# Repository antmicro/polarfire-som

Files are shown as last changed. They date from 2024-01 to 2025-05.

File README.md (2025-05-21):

# PolarFire SoM

Copyright (c) 2023-2025 [Antmicro](https://www.antmicro.com)

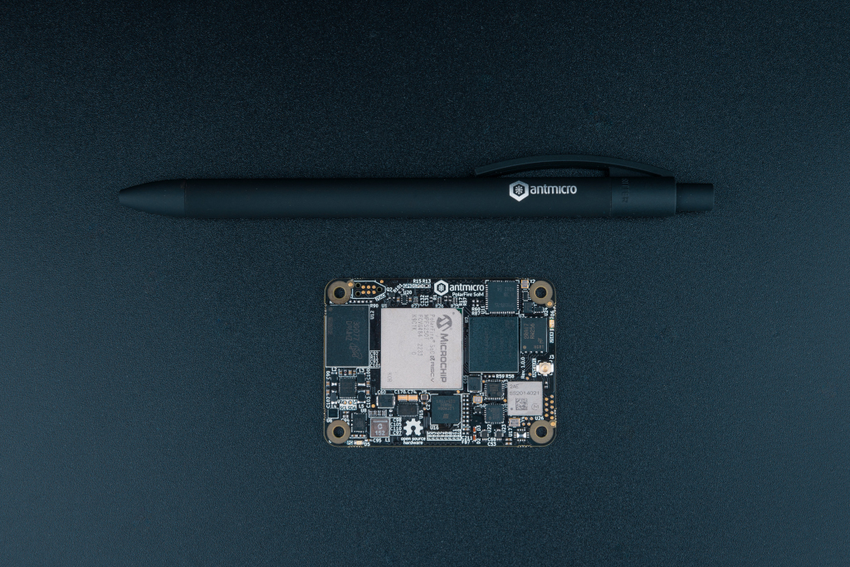
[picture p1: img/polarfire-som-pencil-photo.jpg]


## Overview

This project contains open hardware design files for the Antmicro PolarFire System on Module (SoM) built around Microchip [PolarFire MPFS250T](https://www.microchip.com/en-us/product/mpfs250t) RISC-V System on Chip.
The SoM exposes two 100-pin high density connectors with signal assignment that is electrically compatible with [Raspberry Pi Compute Module 4](https://datasheets.raspberrypi.com/cm4/cm4-datasheet.pdf).

The PCB design files were prepared in KiCad 7.

## Key features

* PolarFire SoC MPFS250T
* 2 GB LPDDR4-1866 SDRAM
* 8 GB eMMC flash memory
* Compact size: 55x40mm 
* Gigabit Ethernet PHY (Ti/[DP83867ISRGZR](https://www.ti.com/lit/gpn/DP83867IS))
* 4-lane PCIe (via MPFS250T built-in XCVR transceivers)
* 2.4 GHz, 5.0 GHz IEEE 802.11 b/g/n/ac WiFi module (Murata/[LBEE5PK2AE](https://www.murata.com/en-eu/products/connectivitymodule/wi-fi-bluetooth/overview/lineup/type2ae))
* Bluetooth 5.2 module (Murata/LBEE5PK2AE)
* HDMI output
* 4-lane MIPI DSI and 4-lane MIPI CSI-2 exposed via Lattice [CrossLink](https://www.latticesemi.com/Products/FPGAandCPLD/CrossLink) (LIF-MD6000-6JMG80I) companion IC
* Additional 2-lane MIPI CSI-2 camera port, when working in 1.8V logic
* On-board power sequencing and voltage regulation based on a single 5V supply

## Project structure

The main directory contains KiCad PCB project files, a LICENSE, and a README.
The remaining files are stored in the following directories:

* `doc` - contains schematics in PDF format
* `assets` - contains visual assets for showcasing this design on [Open Hardware Portal](https://openhardware.antmicro.com).
* `img` - contains graphics for this README

## Licensing

This project is published under the [Apache-2.0](LICENSE) license.

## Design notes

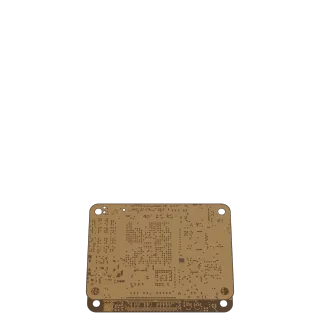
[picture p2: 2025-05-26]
assets/previews/layer14_thumbnail.webp

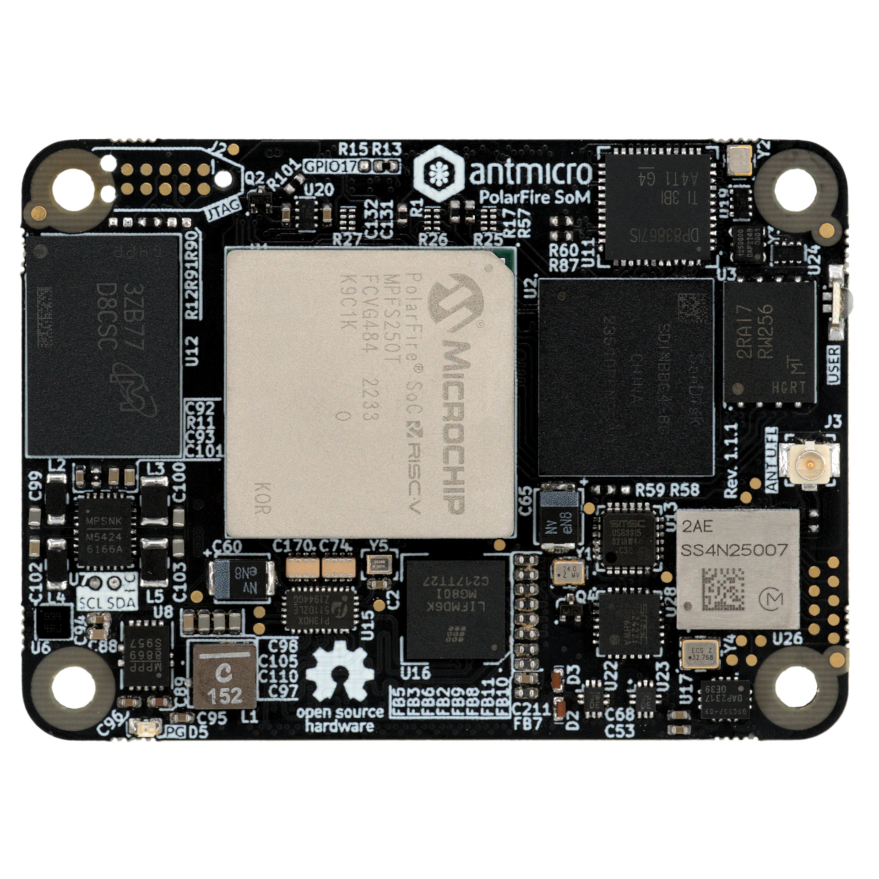
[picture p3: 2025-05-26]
assets/previews/orthoT_photo.png

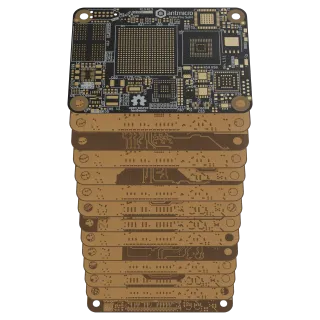
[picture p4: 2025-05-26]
assets/previews/layer1_thumbnail.webp

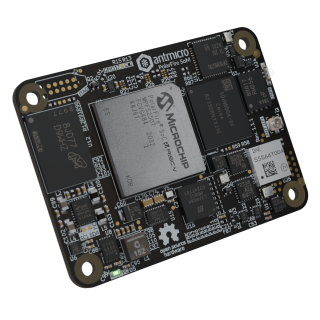
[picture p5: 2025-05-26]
assets/previews/leftT_thumbnail.png

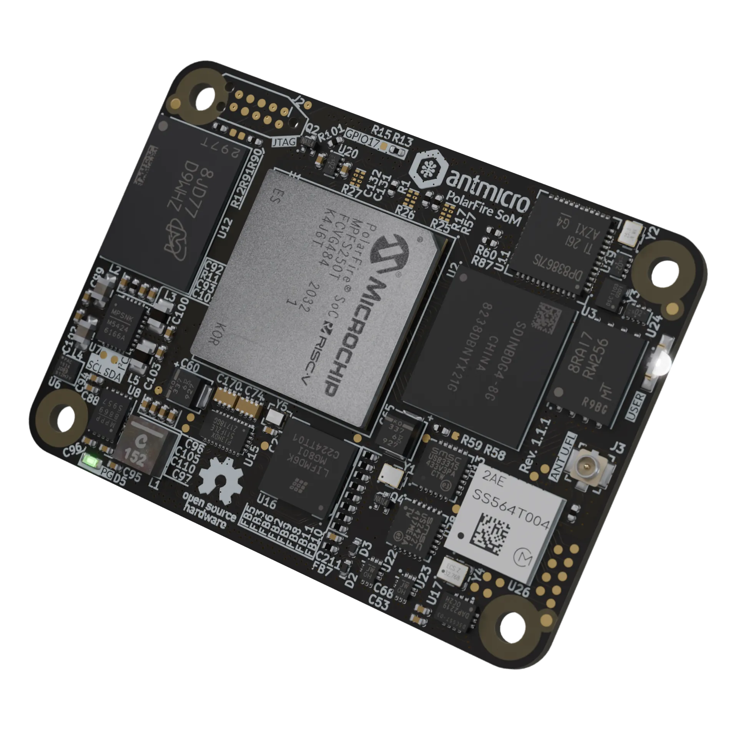
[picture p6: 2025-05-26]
assets/previews/rightT.webp

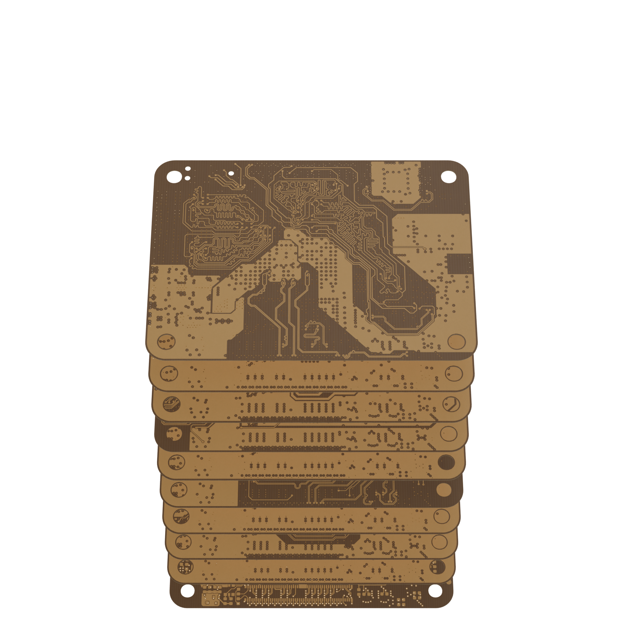
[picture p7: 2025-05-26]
assets/previews/layer6.png

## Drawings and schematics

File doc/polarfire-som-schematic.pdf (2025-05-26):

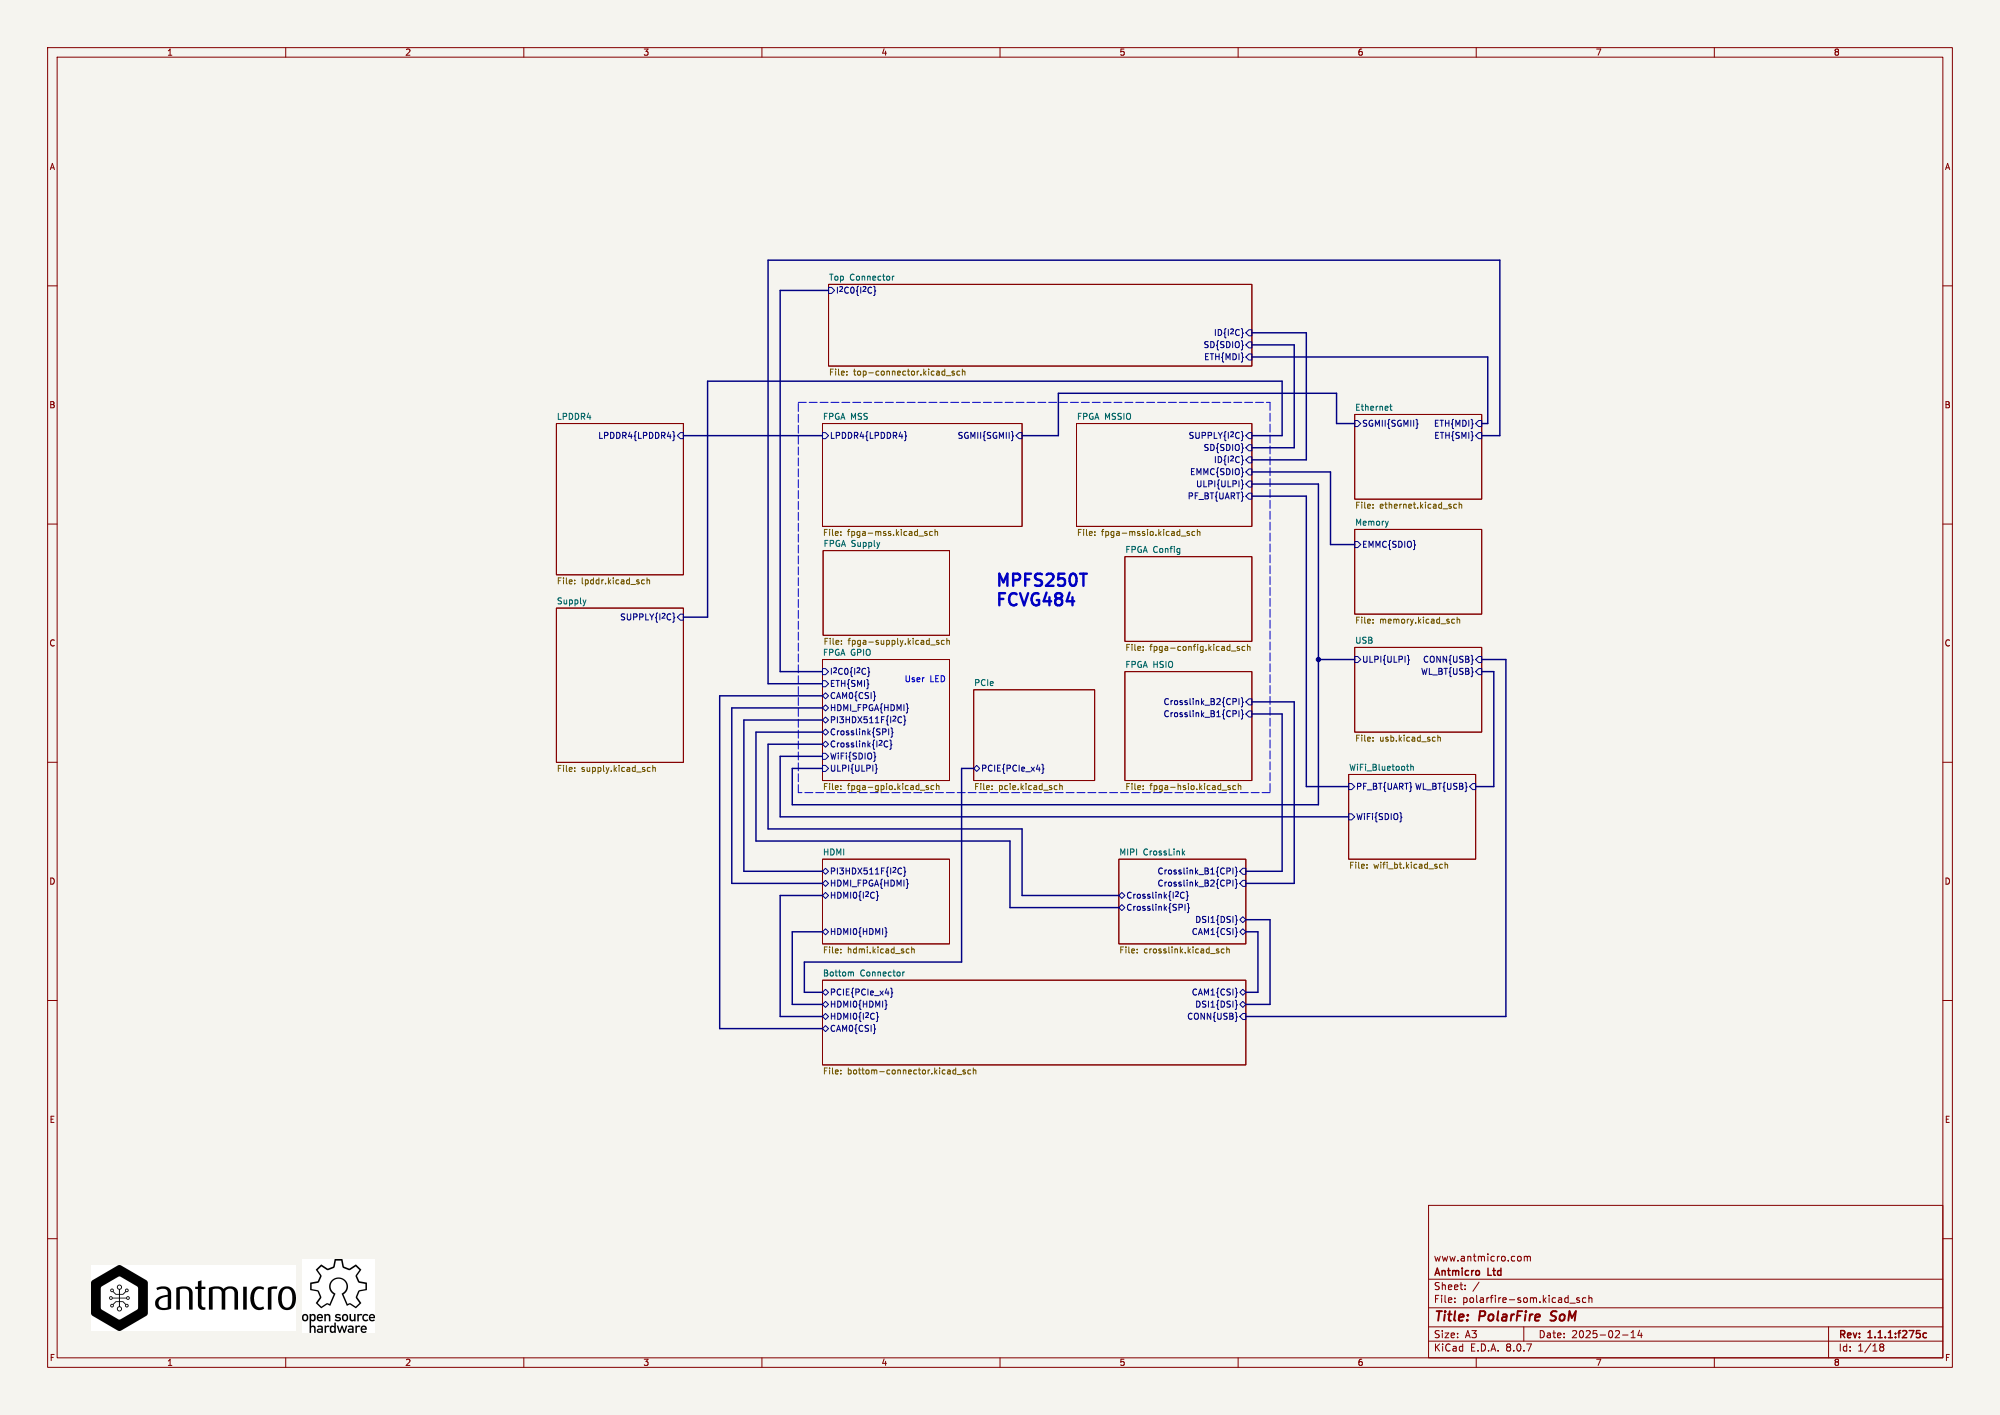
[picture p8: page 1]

Top Connector File: top-connector.kicad_sch

SD{SDIO}
ETH{SMI} Ethernet File: ethernet.kicad_sch ETH{MDI}

File: usb.kicad_sch EMMC{SDIO}

File: fpga-mssio.kicad_sch FPGA Config File: fpga-config.kicad_sch FPGA Supply File: fpga-supply.kicad_sch

ULPI{ULPI} FPGA GPIO

Crosslink{SPI} MIPI CrossLink File: crosslink.kicad_sch PCIE{PCIe_x4}

Id: 1/18 Title: PolarFire SoM

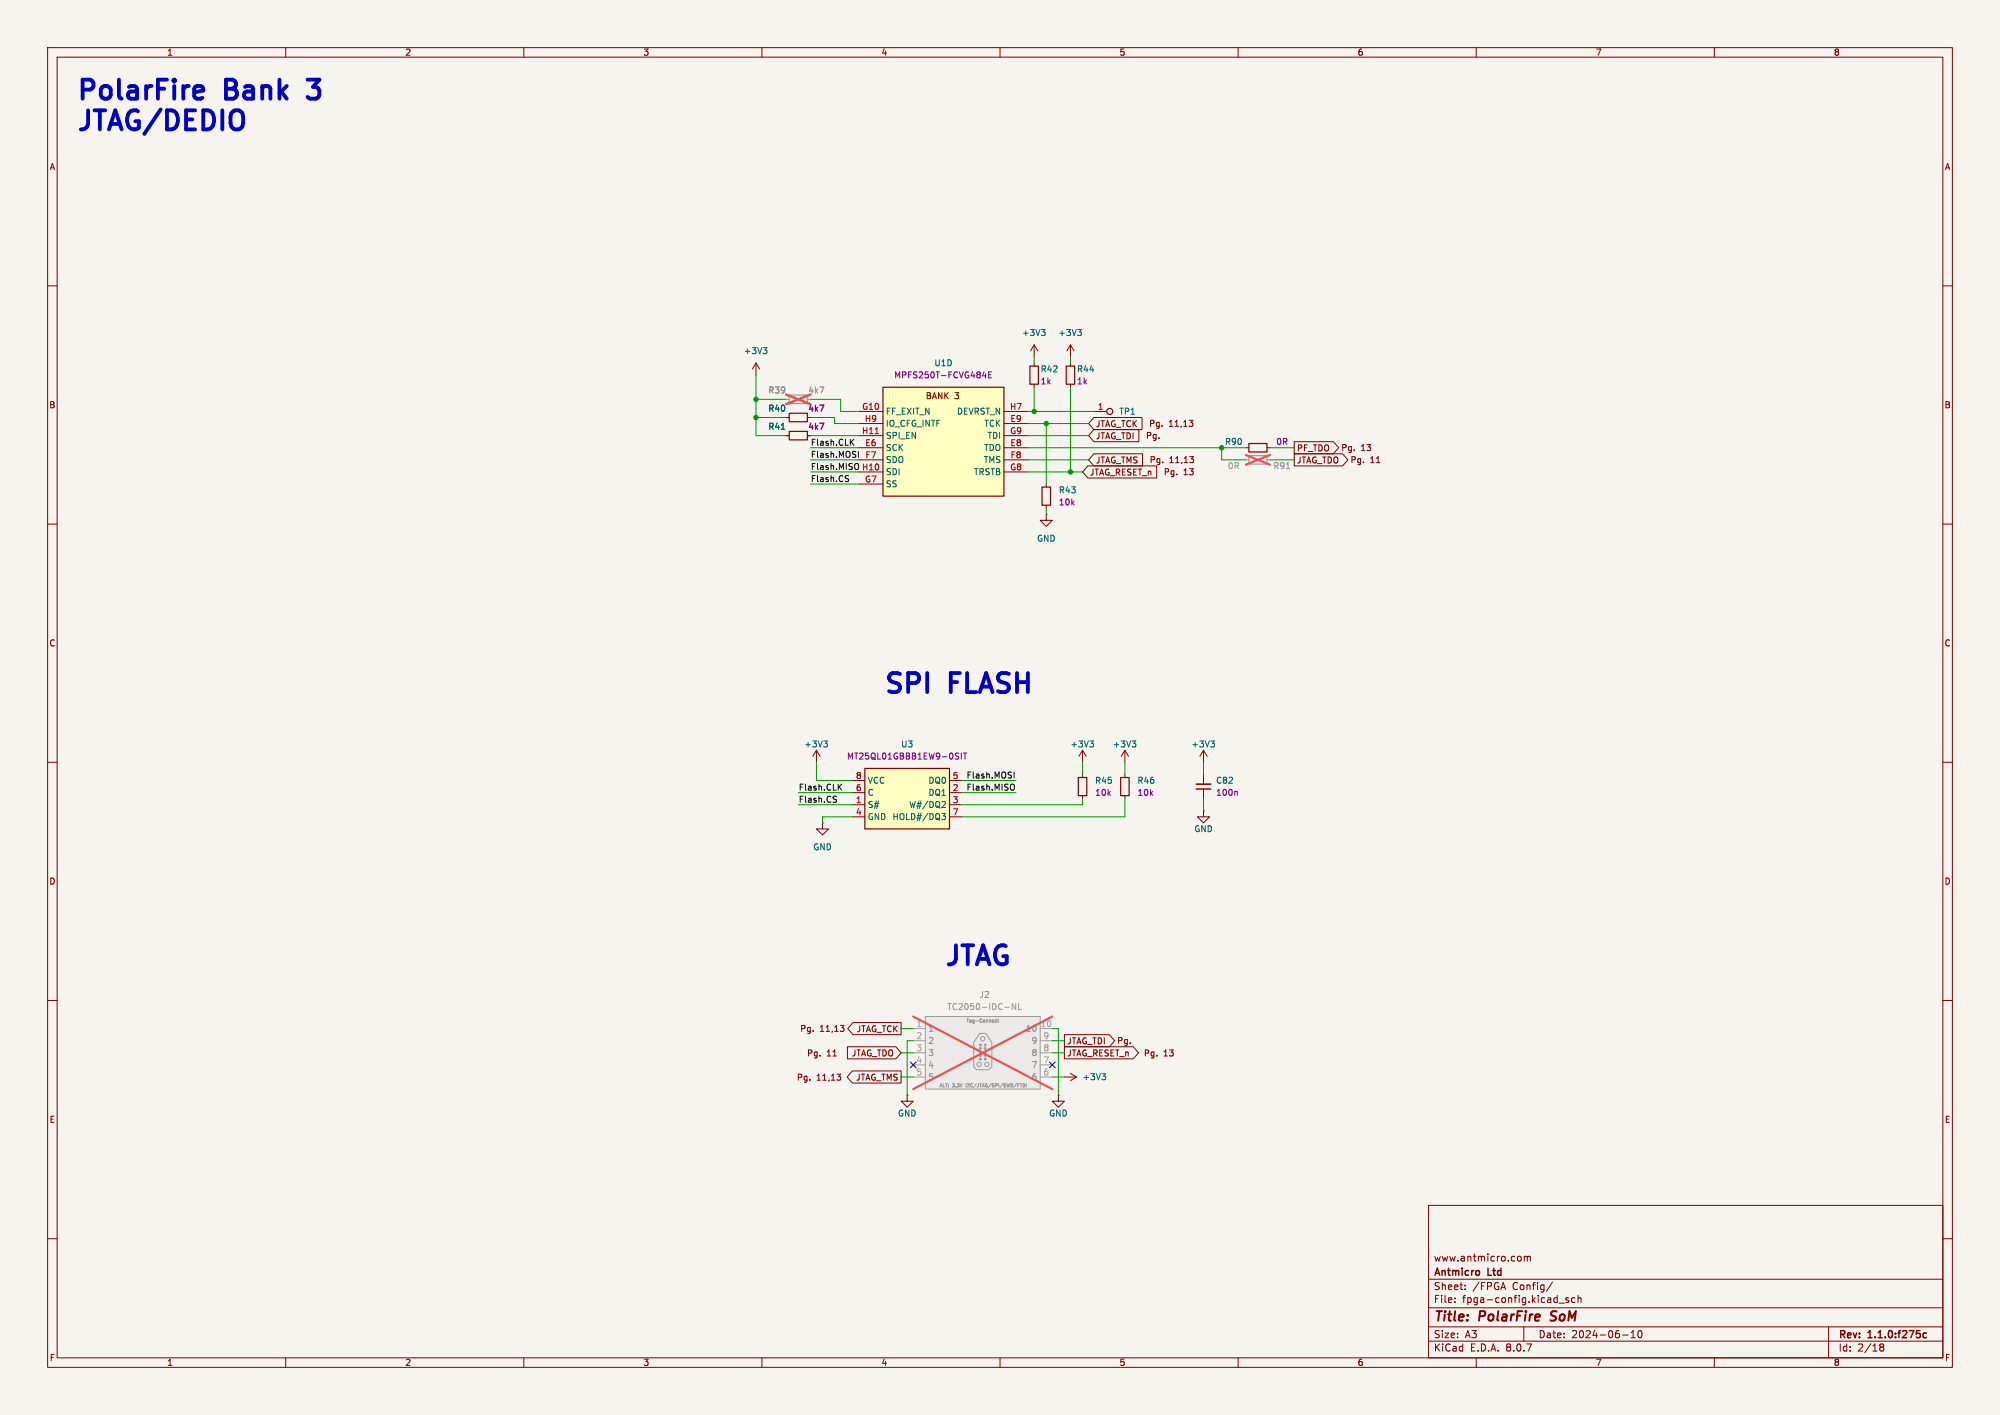
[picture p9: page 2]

Flash.MOSI PolarFire Bank 3
JTAG/DEDIO

Flash.MOSI Flash.CLK

Id: 2/18 Title: PolarFire SoM

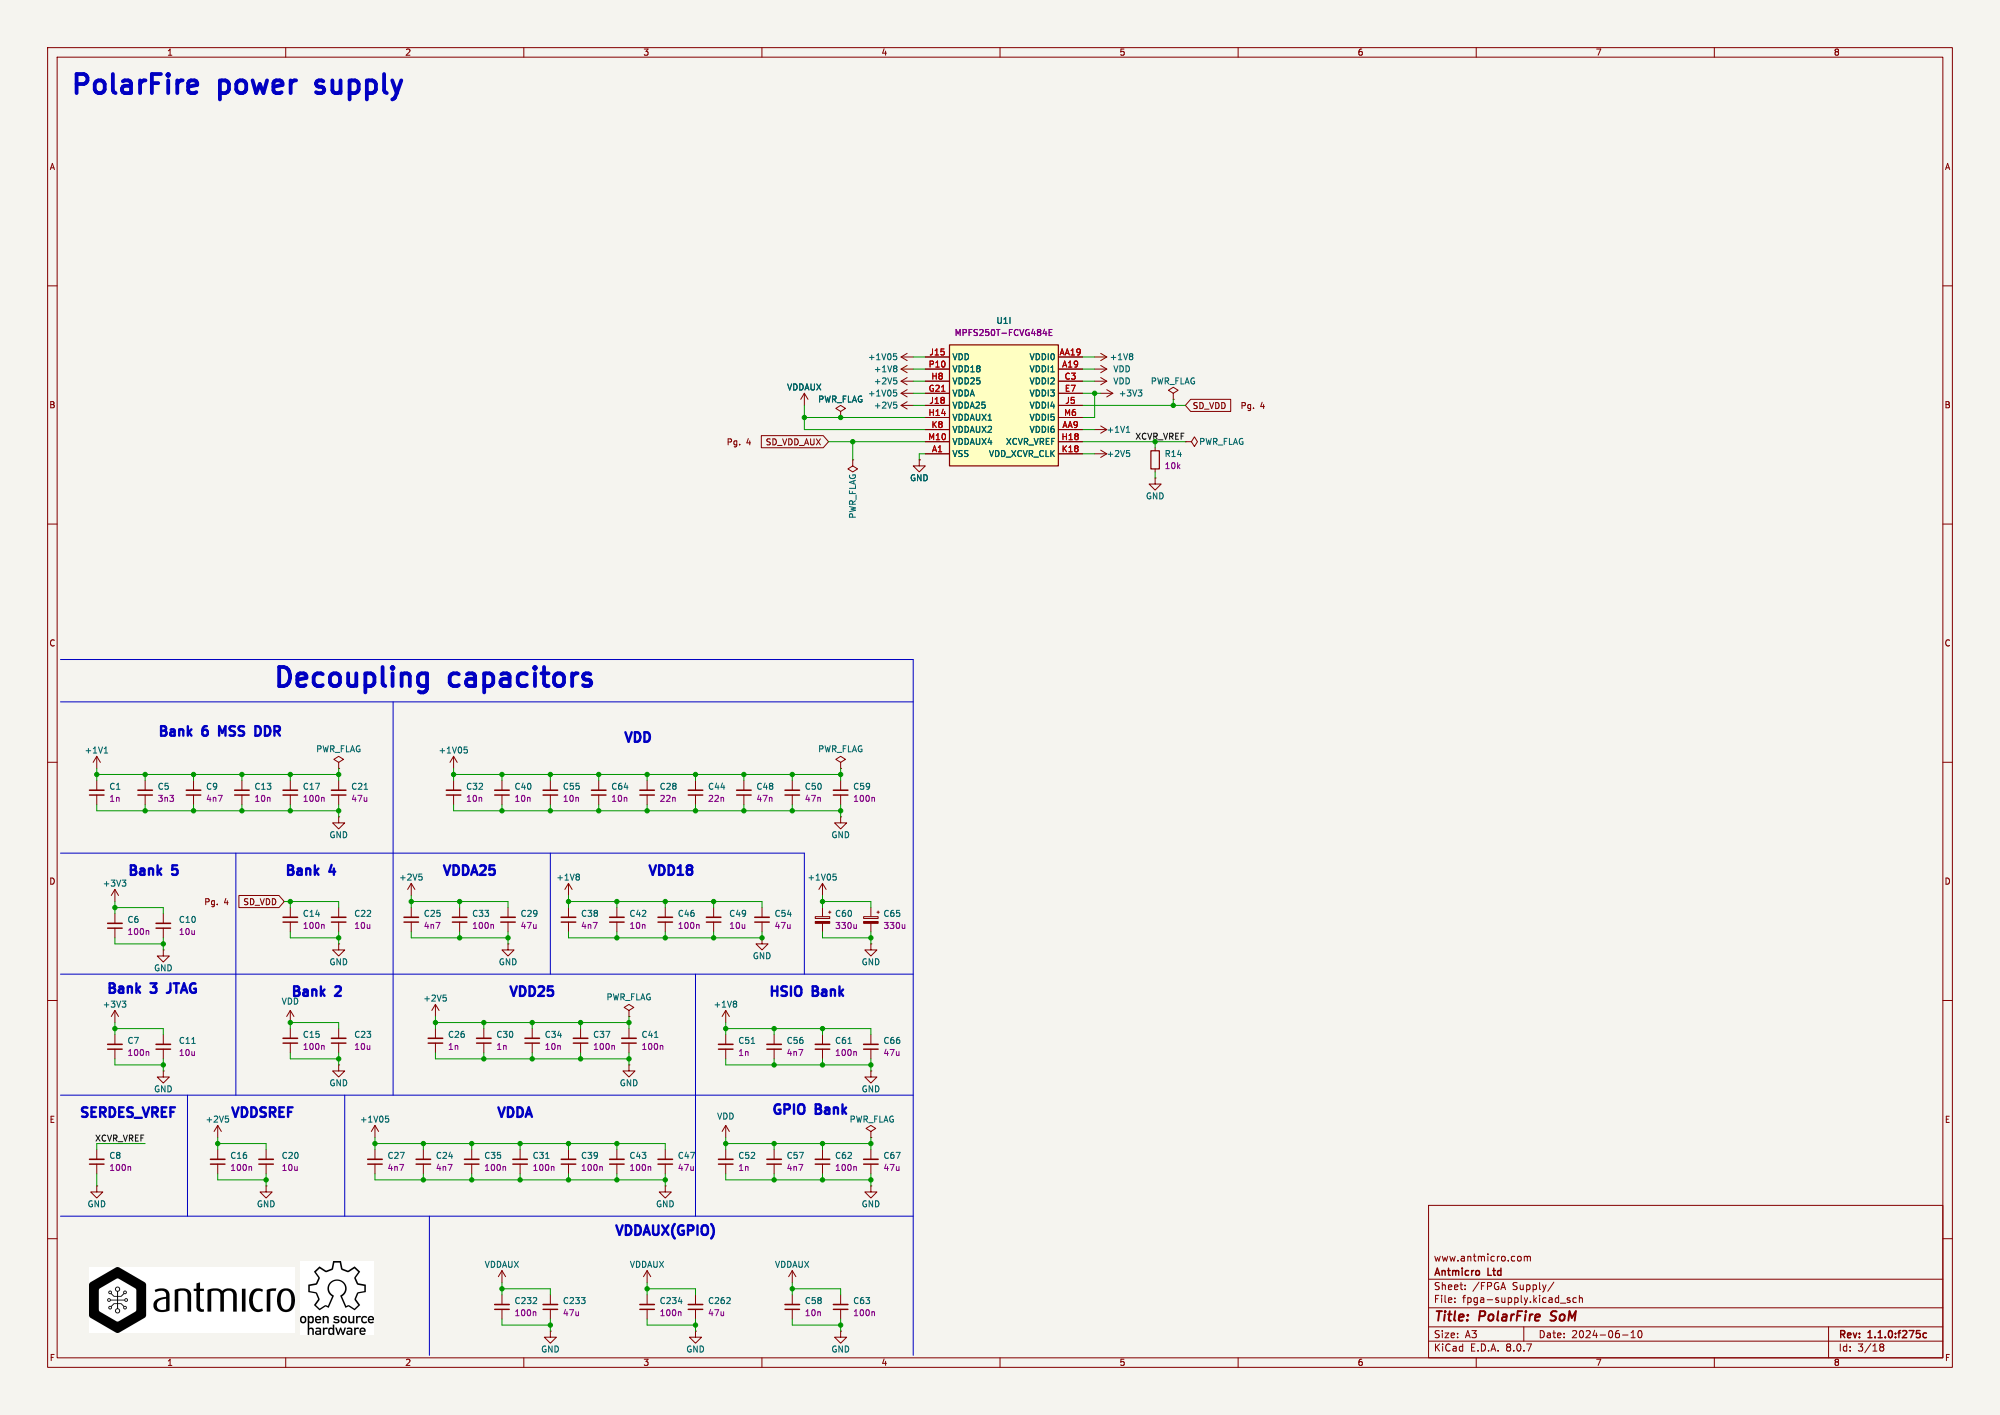
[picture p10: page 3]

Id: 3/18 Title: PolarFire SoM

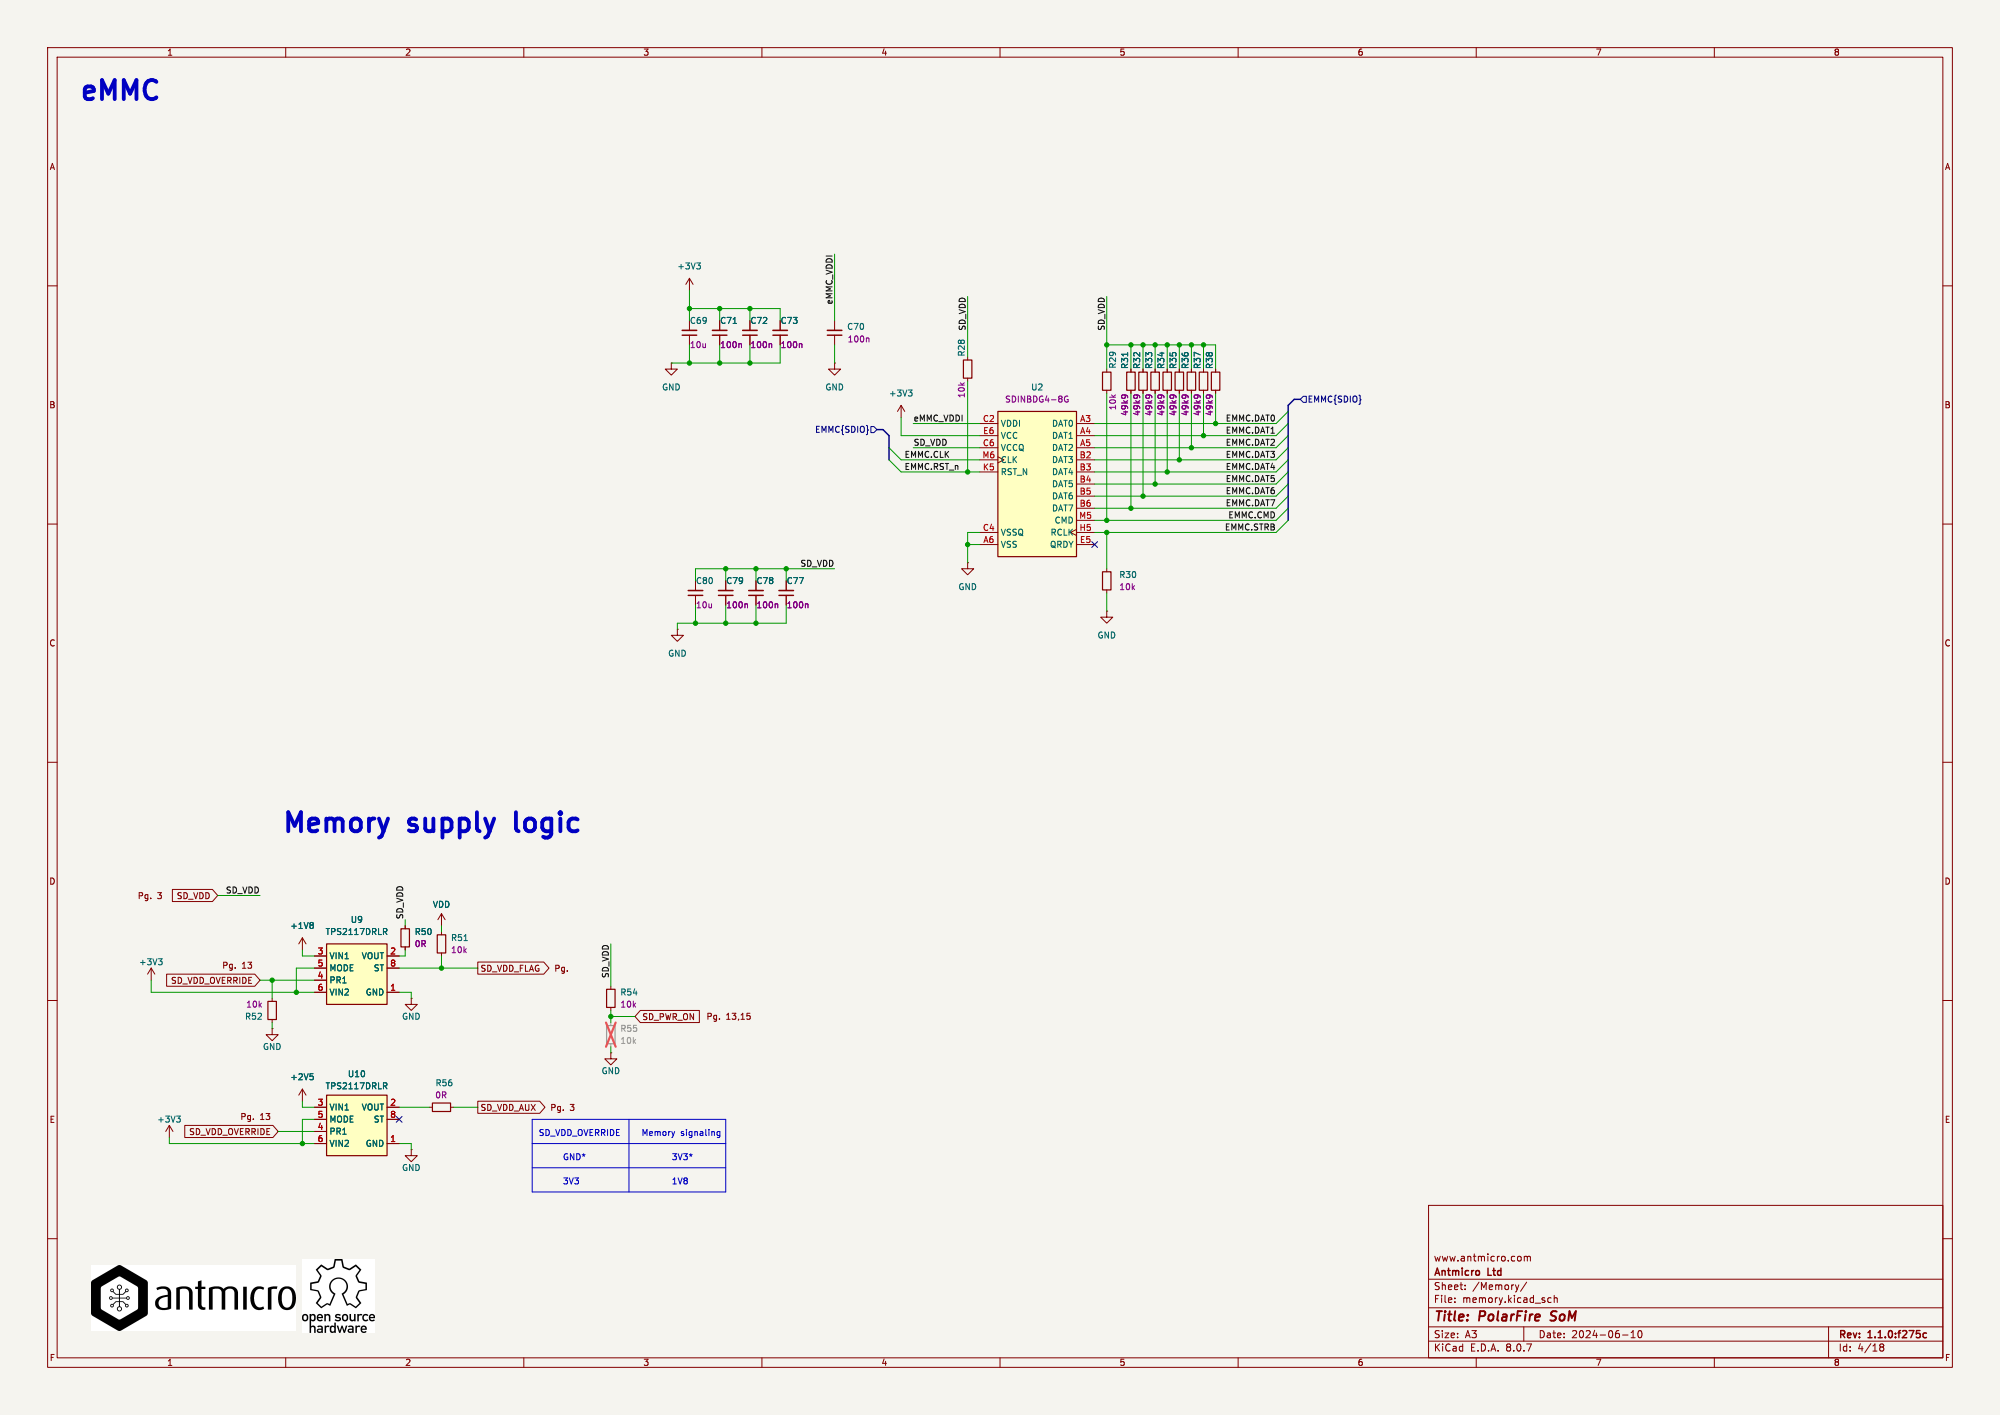
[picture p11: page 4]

EMMC.DAT1 EMMC.DAT0 EMMC.DAT4 EMMC.DAT6 EMMC.DAT2 EMMC.RST_n

GND* 3V3 SD_VDD_OVERRIDE Memory supply logic

Id: 4/18 Title: PolarFire SoM

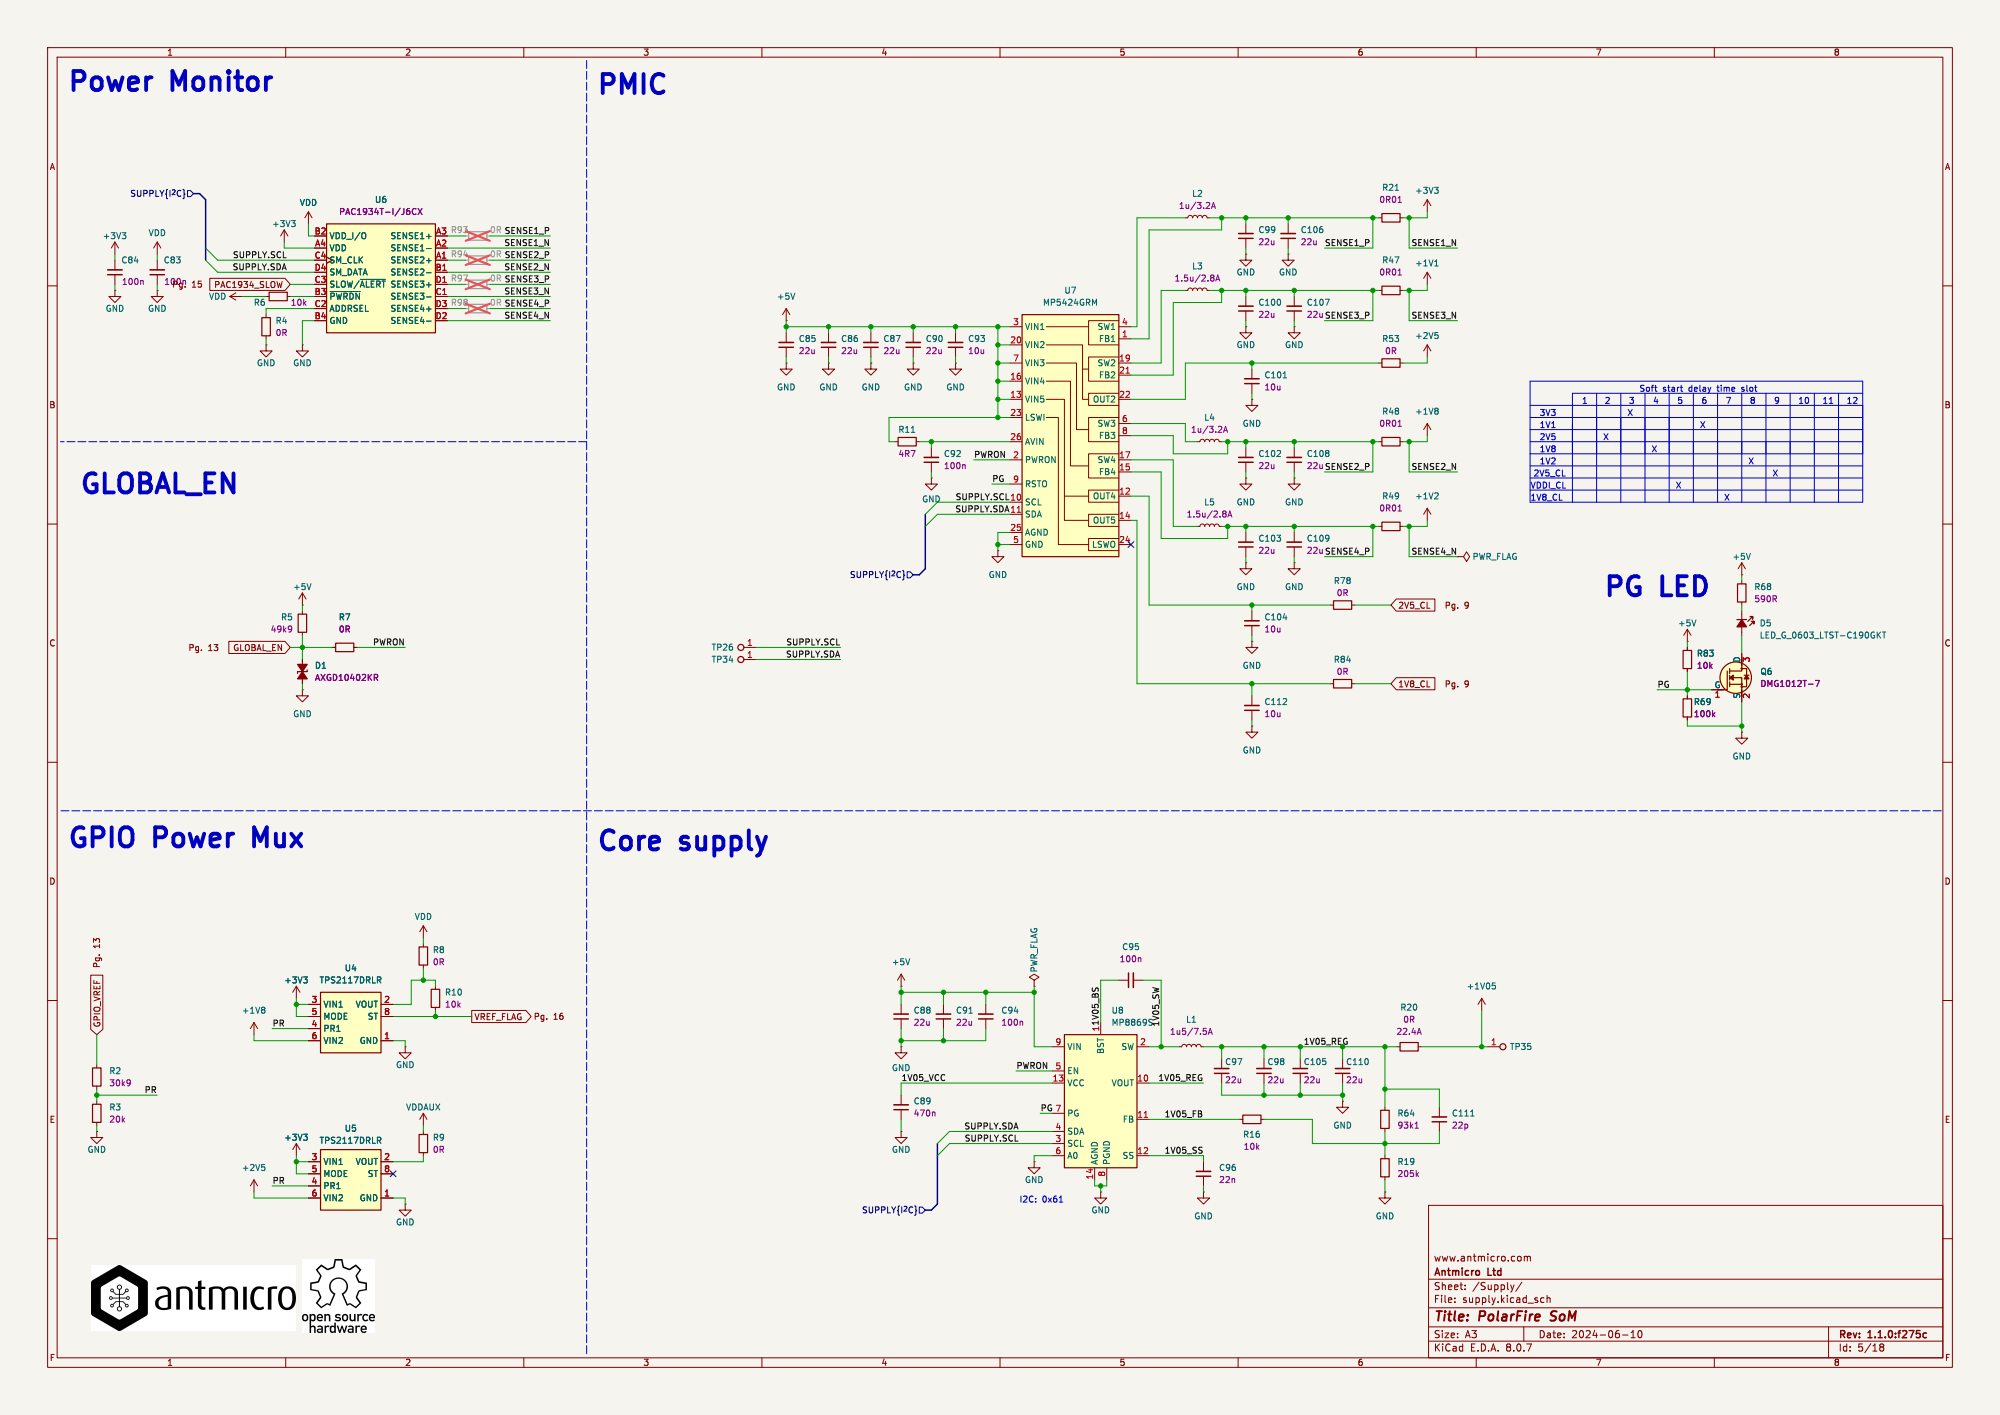
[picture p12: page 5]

SUPPLY.SCL SUPPLY.SDA

1 VOUT 10 FB 11 SS 12 VCC 13 AGND 14 SW 2 SCL 3 SDA 4 EN 5 A0 6 PG 7 PGND

Id: 5/18 Title: PolarFire SoM

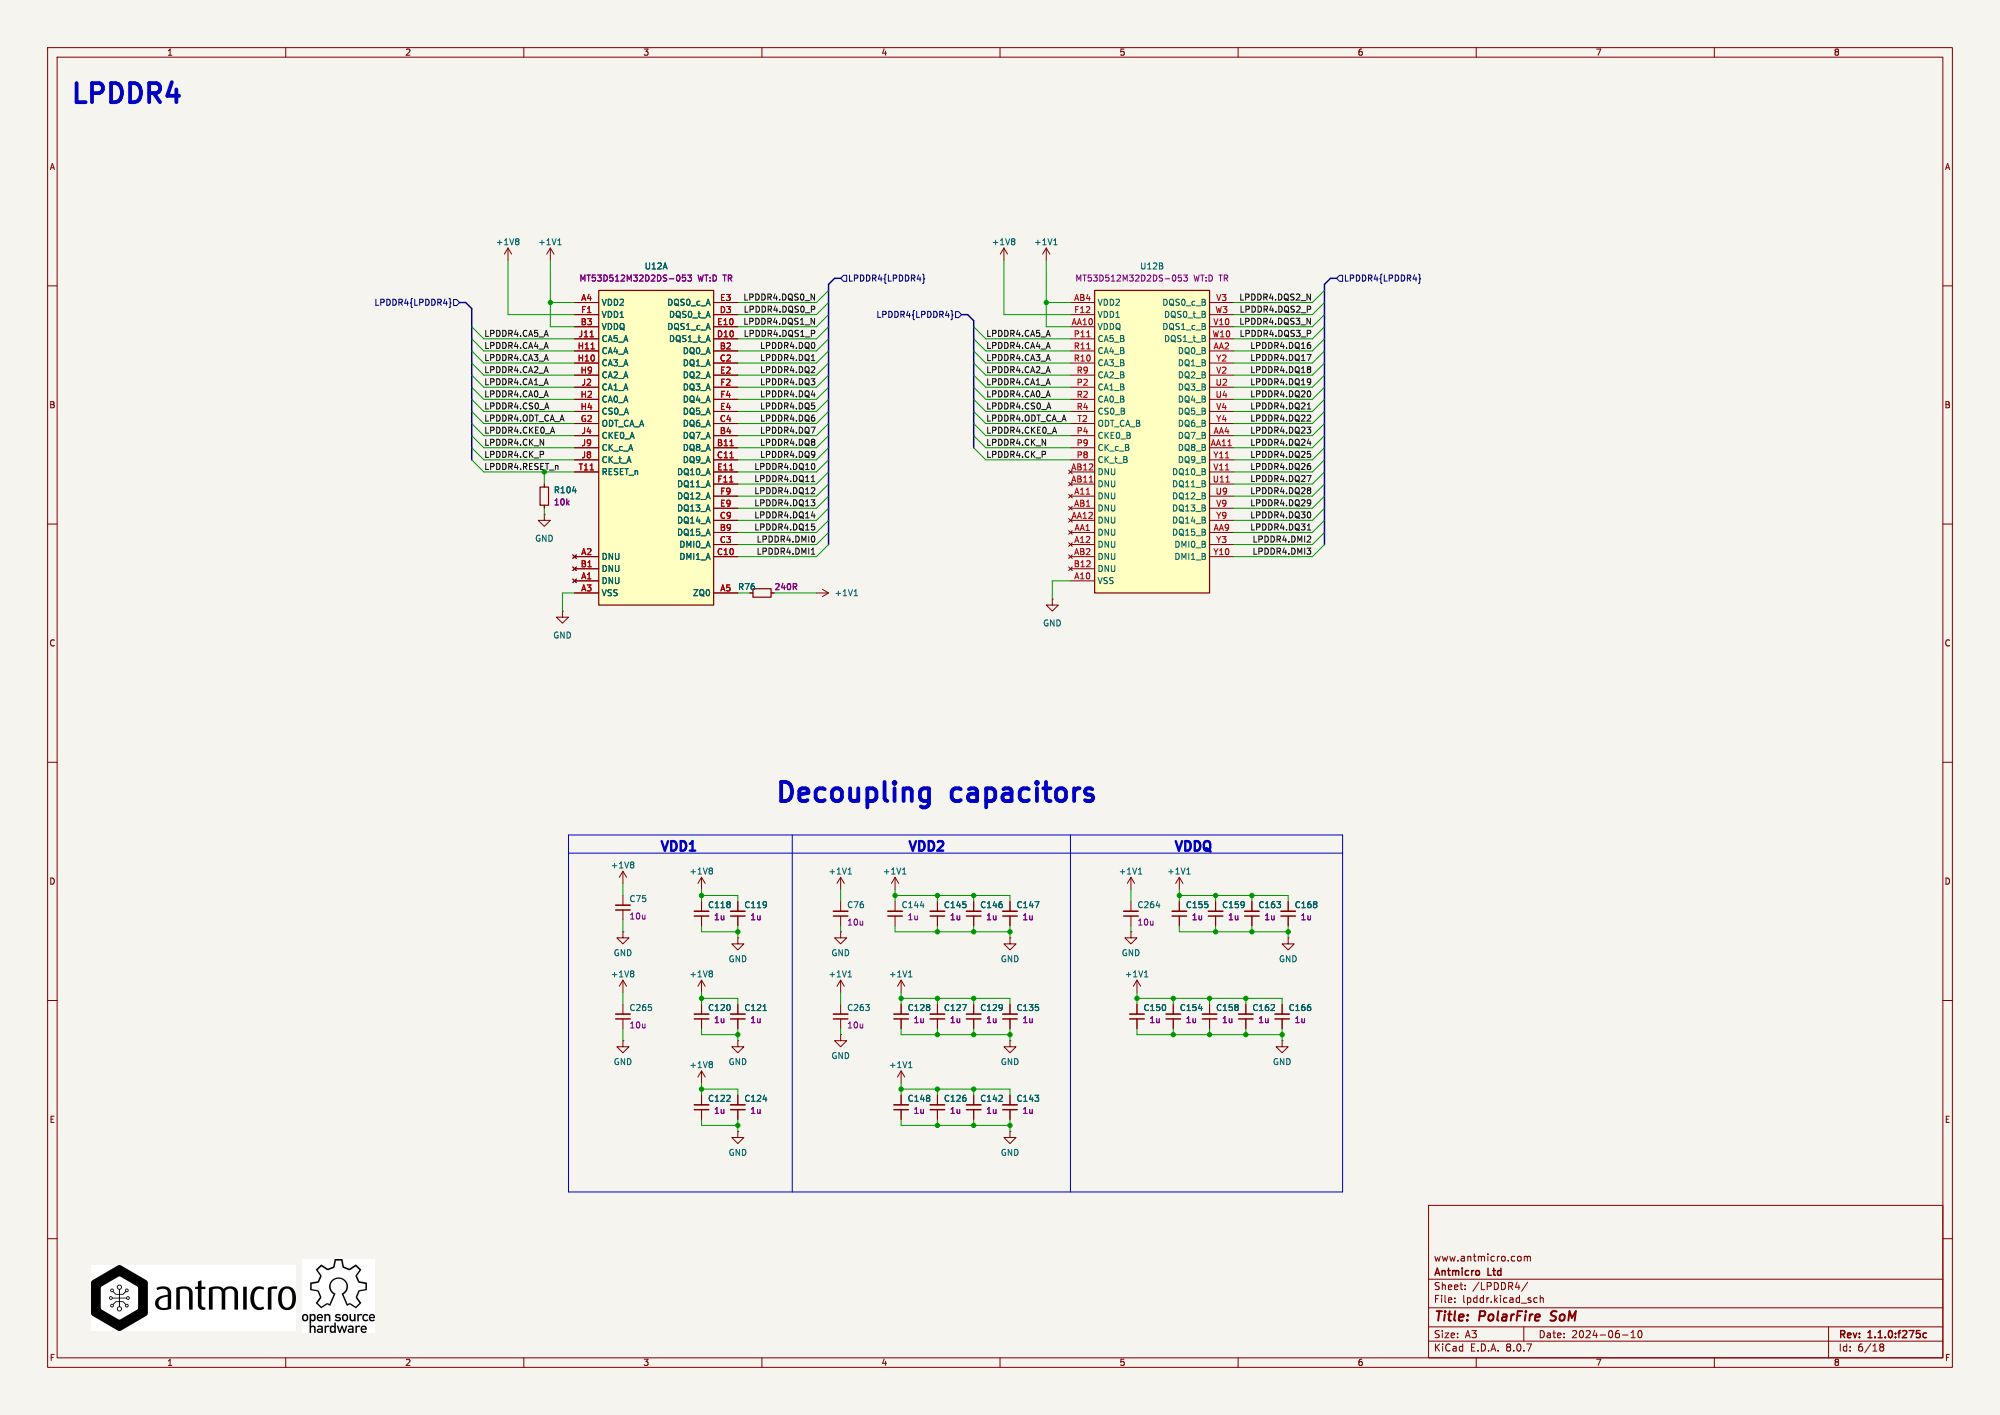
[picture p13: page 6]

Id: 6/18 Title: PolarFire SoM

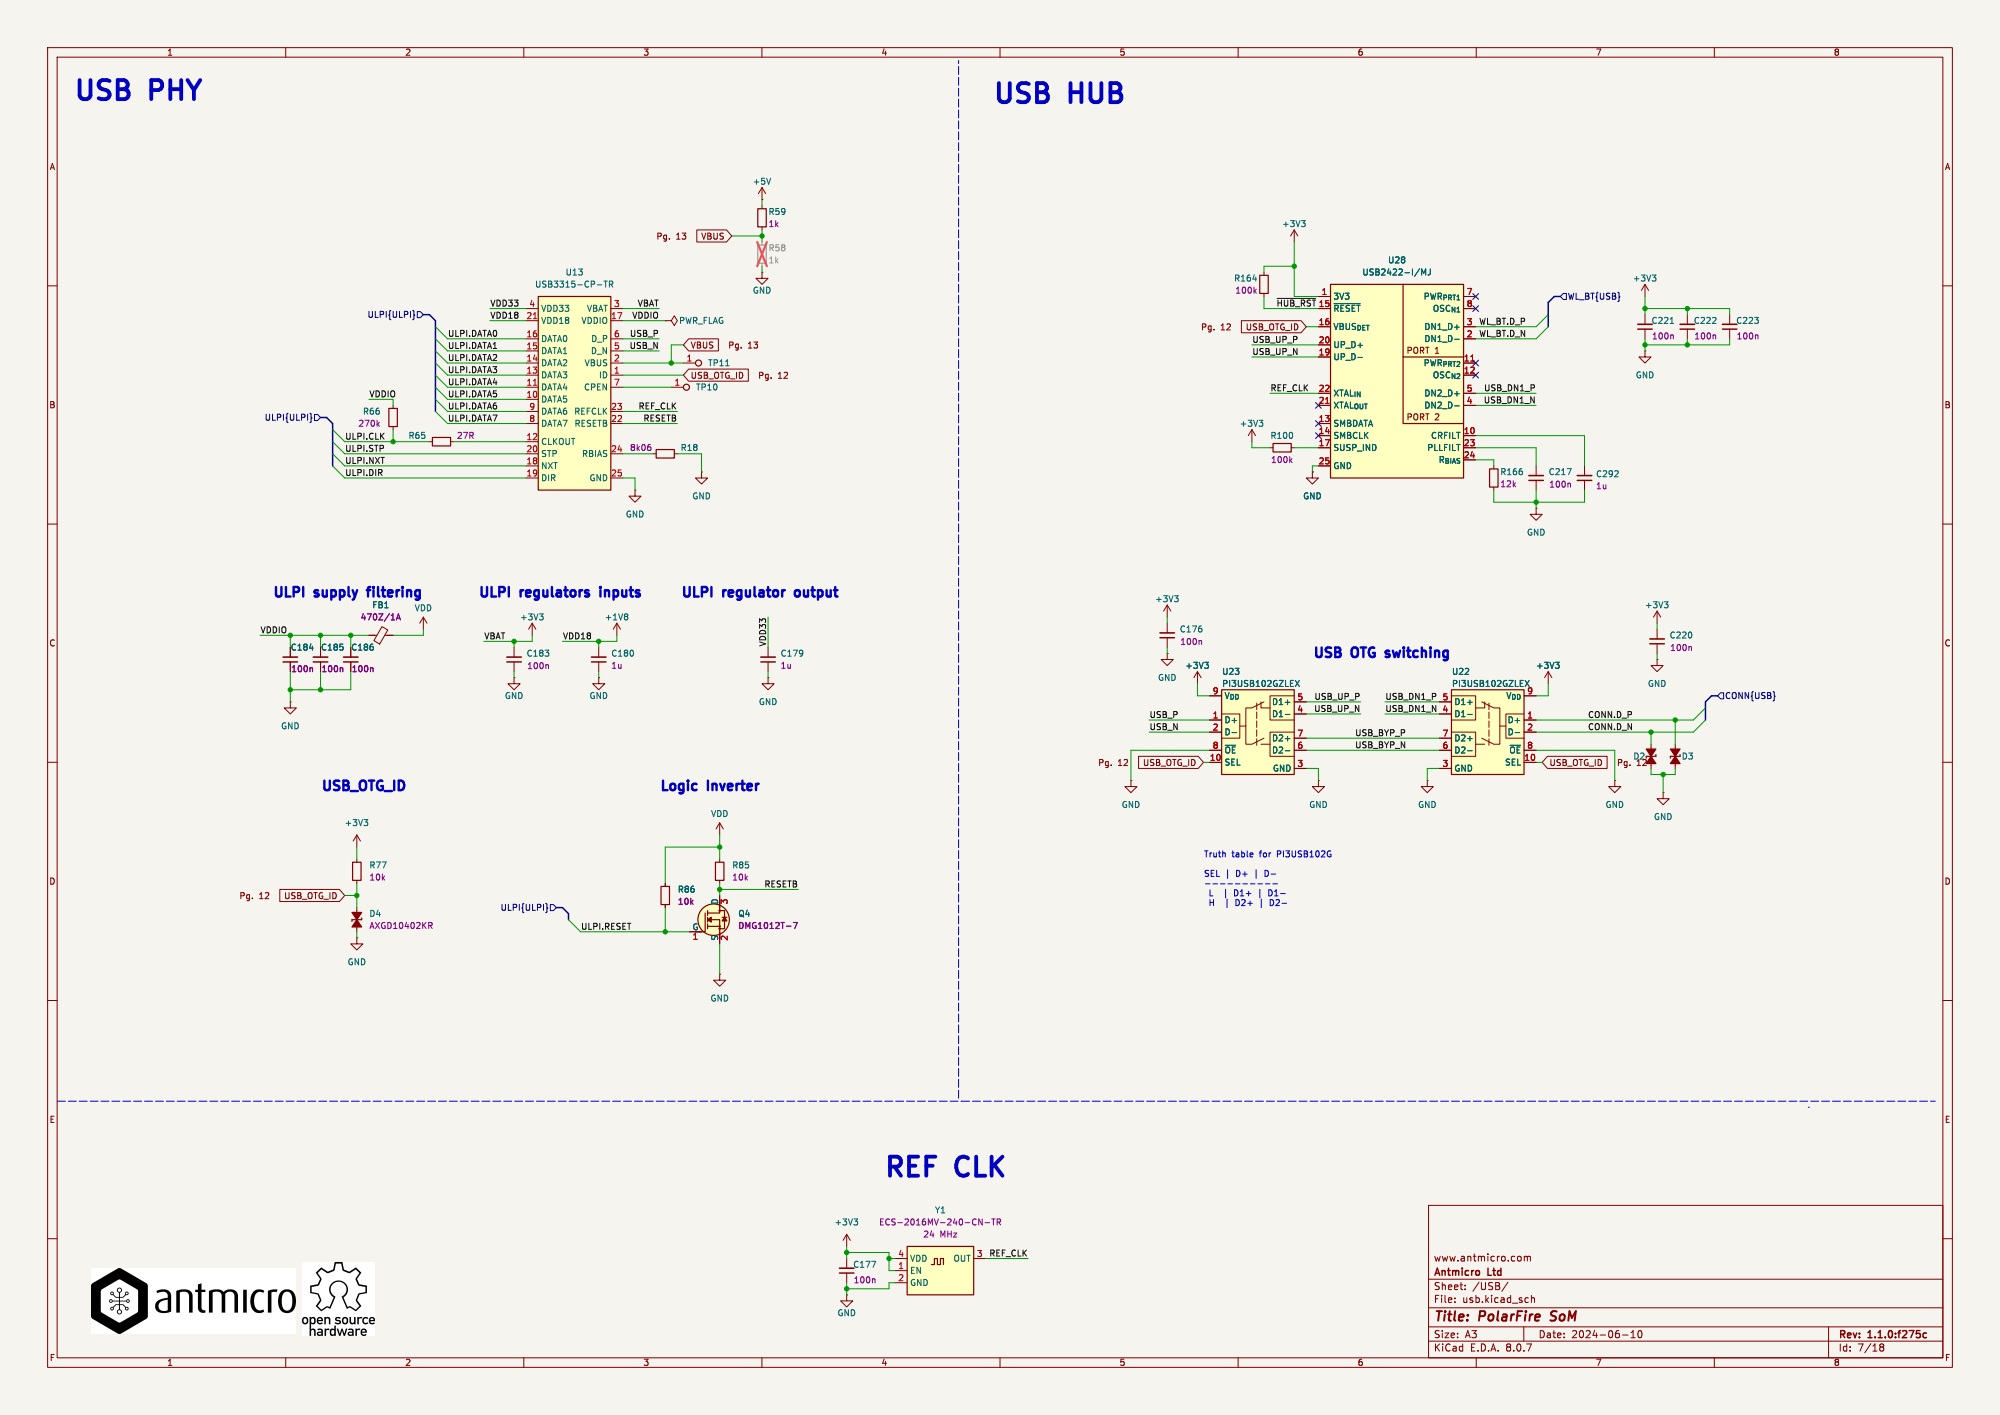
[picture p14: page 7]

3 Q4 DMG1012T-7 GND GND GND GND GND GND
VDD

Id: 7/18 Title: PolarFire SoM

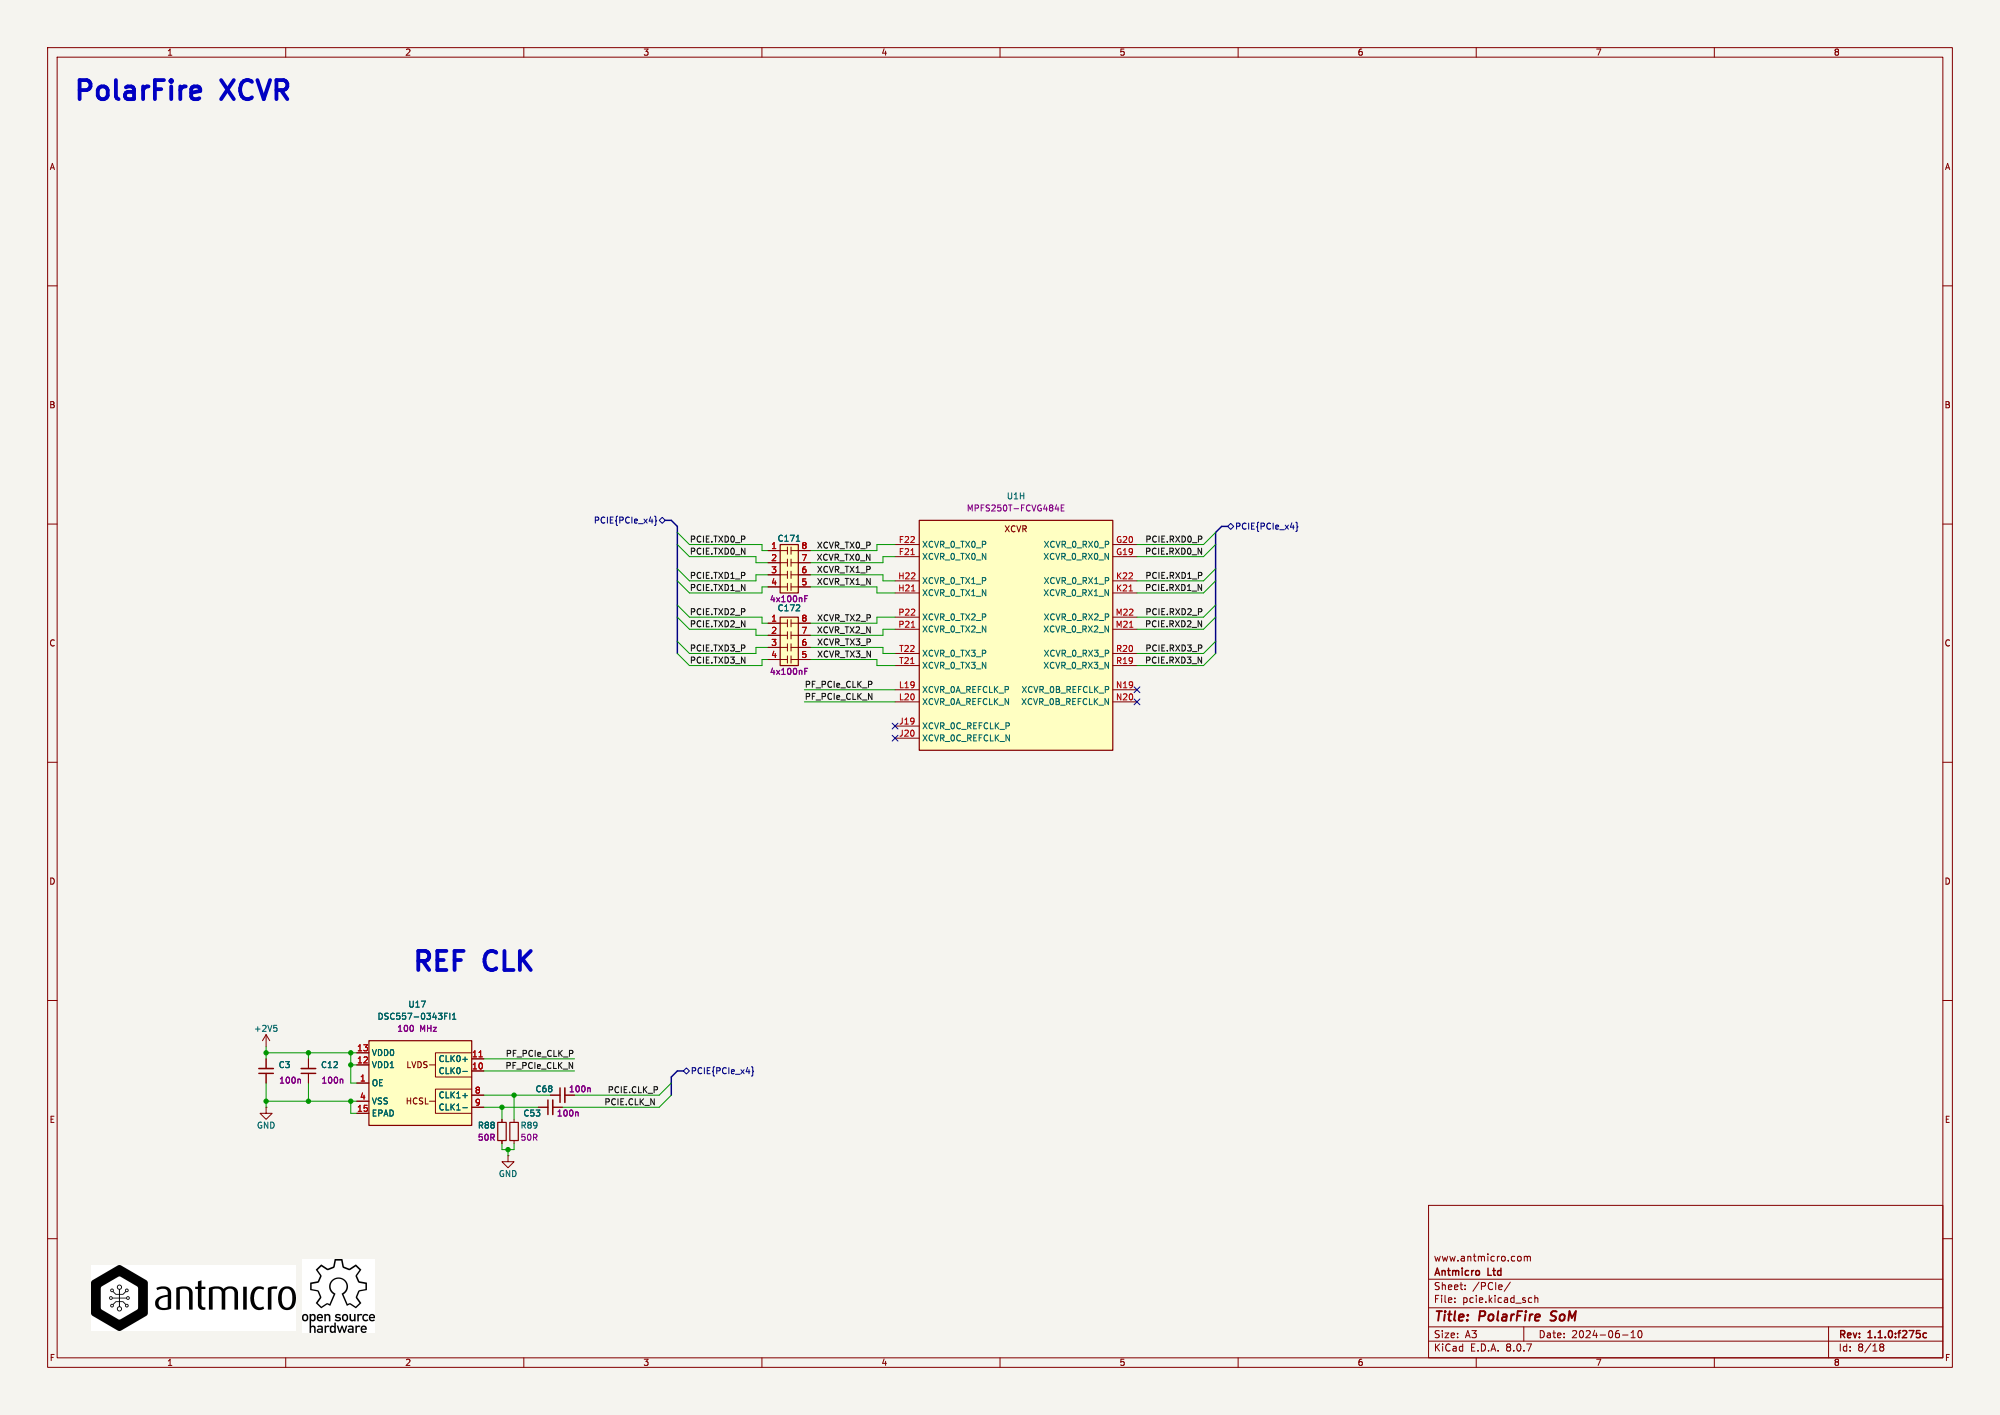
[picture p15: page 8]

Id: 8/18 Title: PolarFire SoM

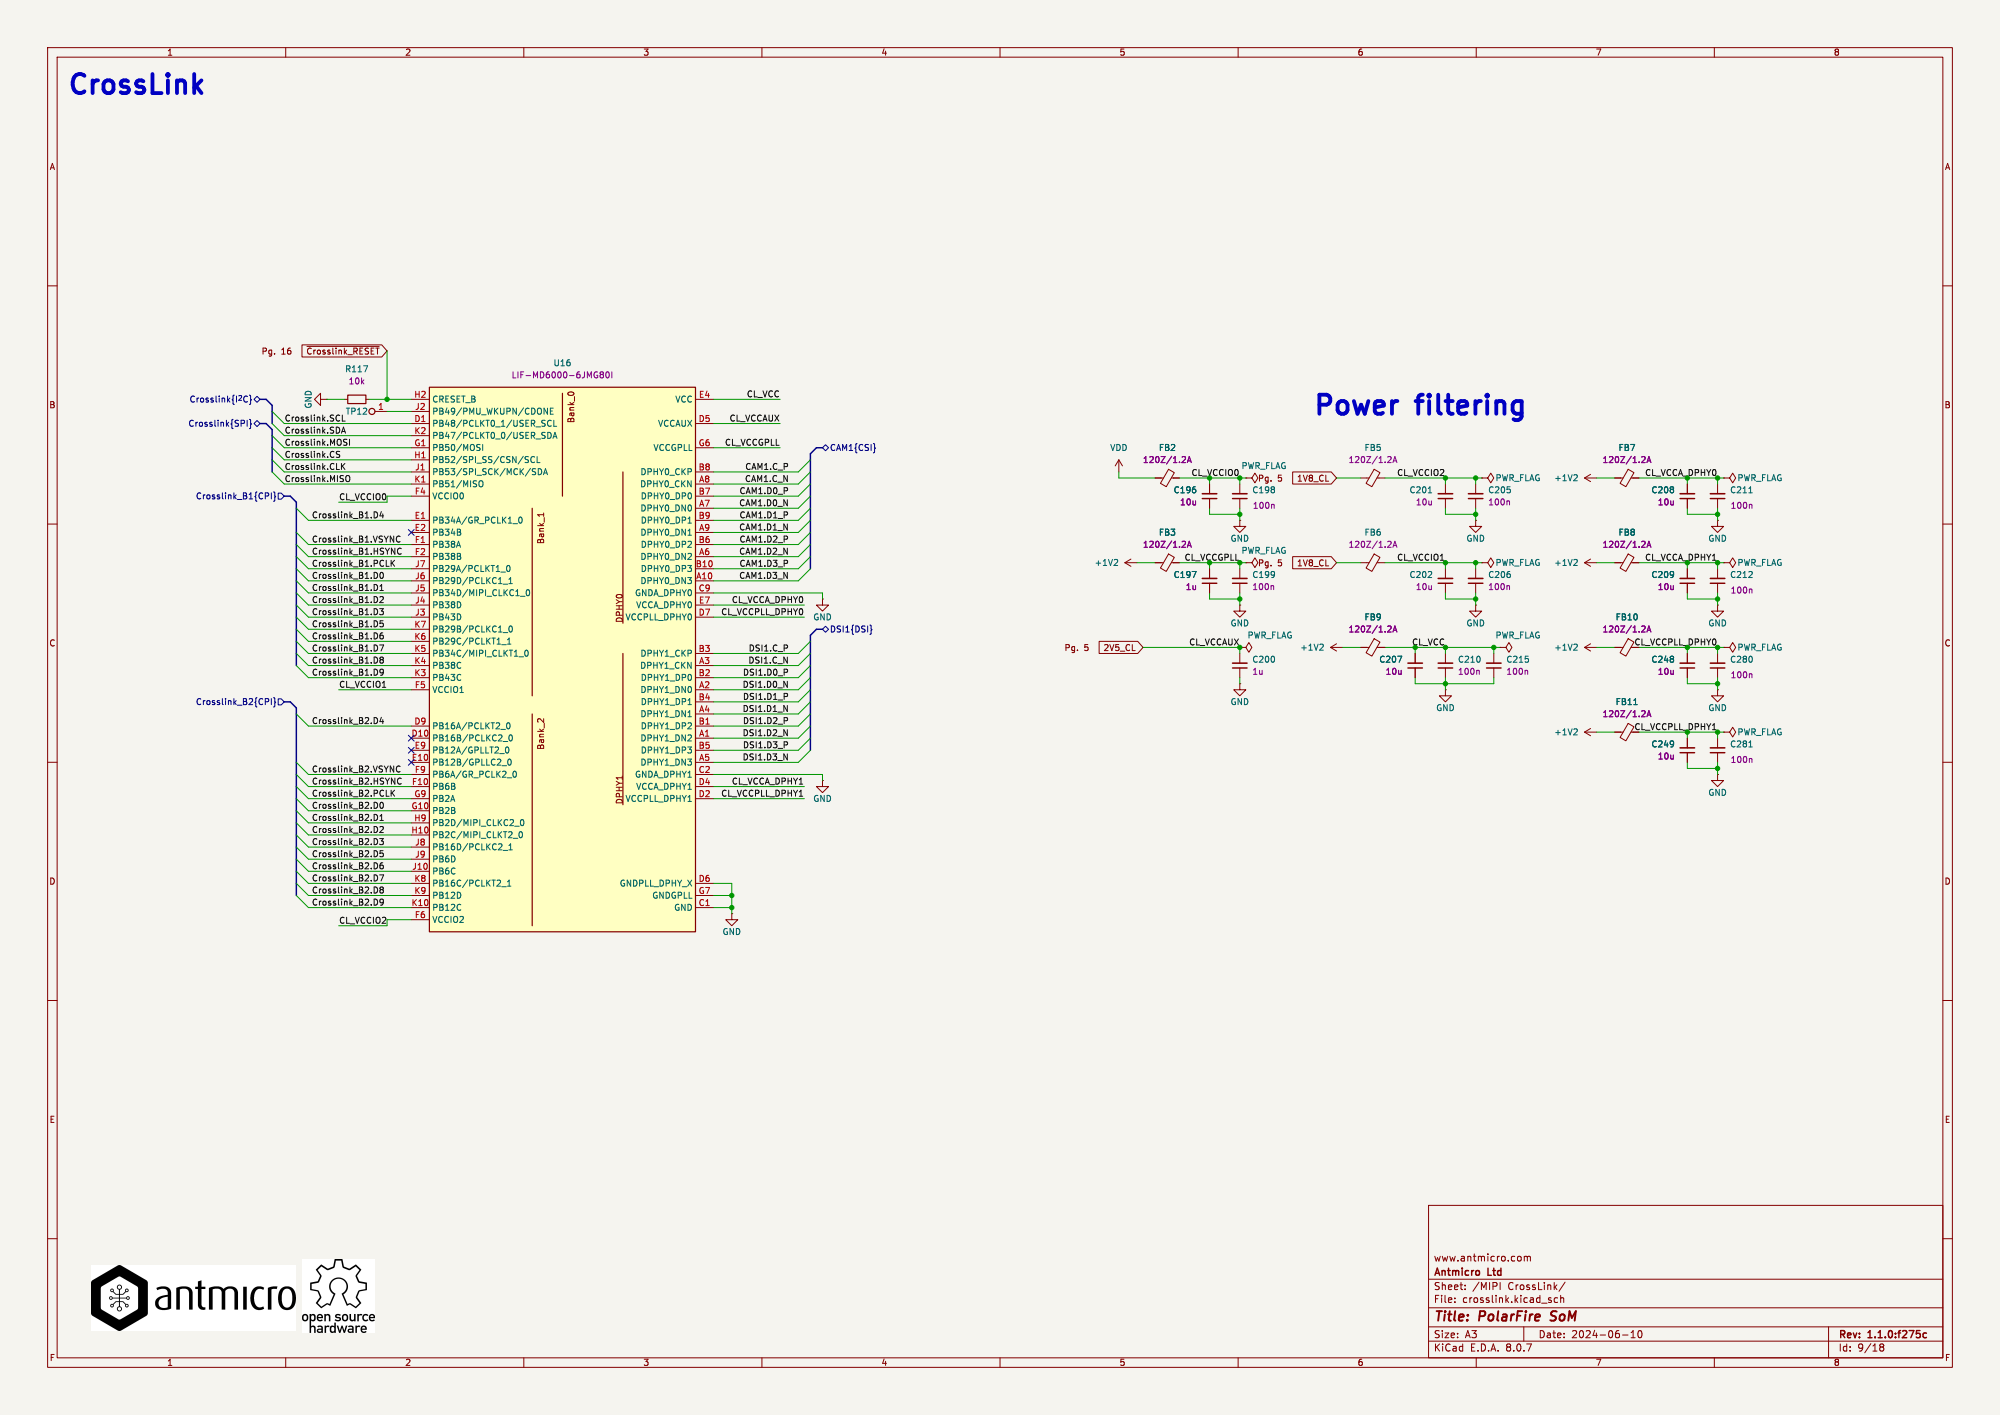
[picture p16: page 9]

Id: 9/18 Title: PolarFire SoM

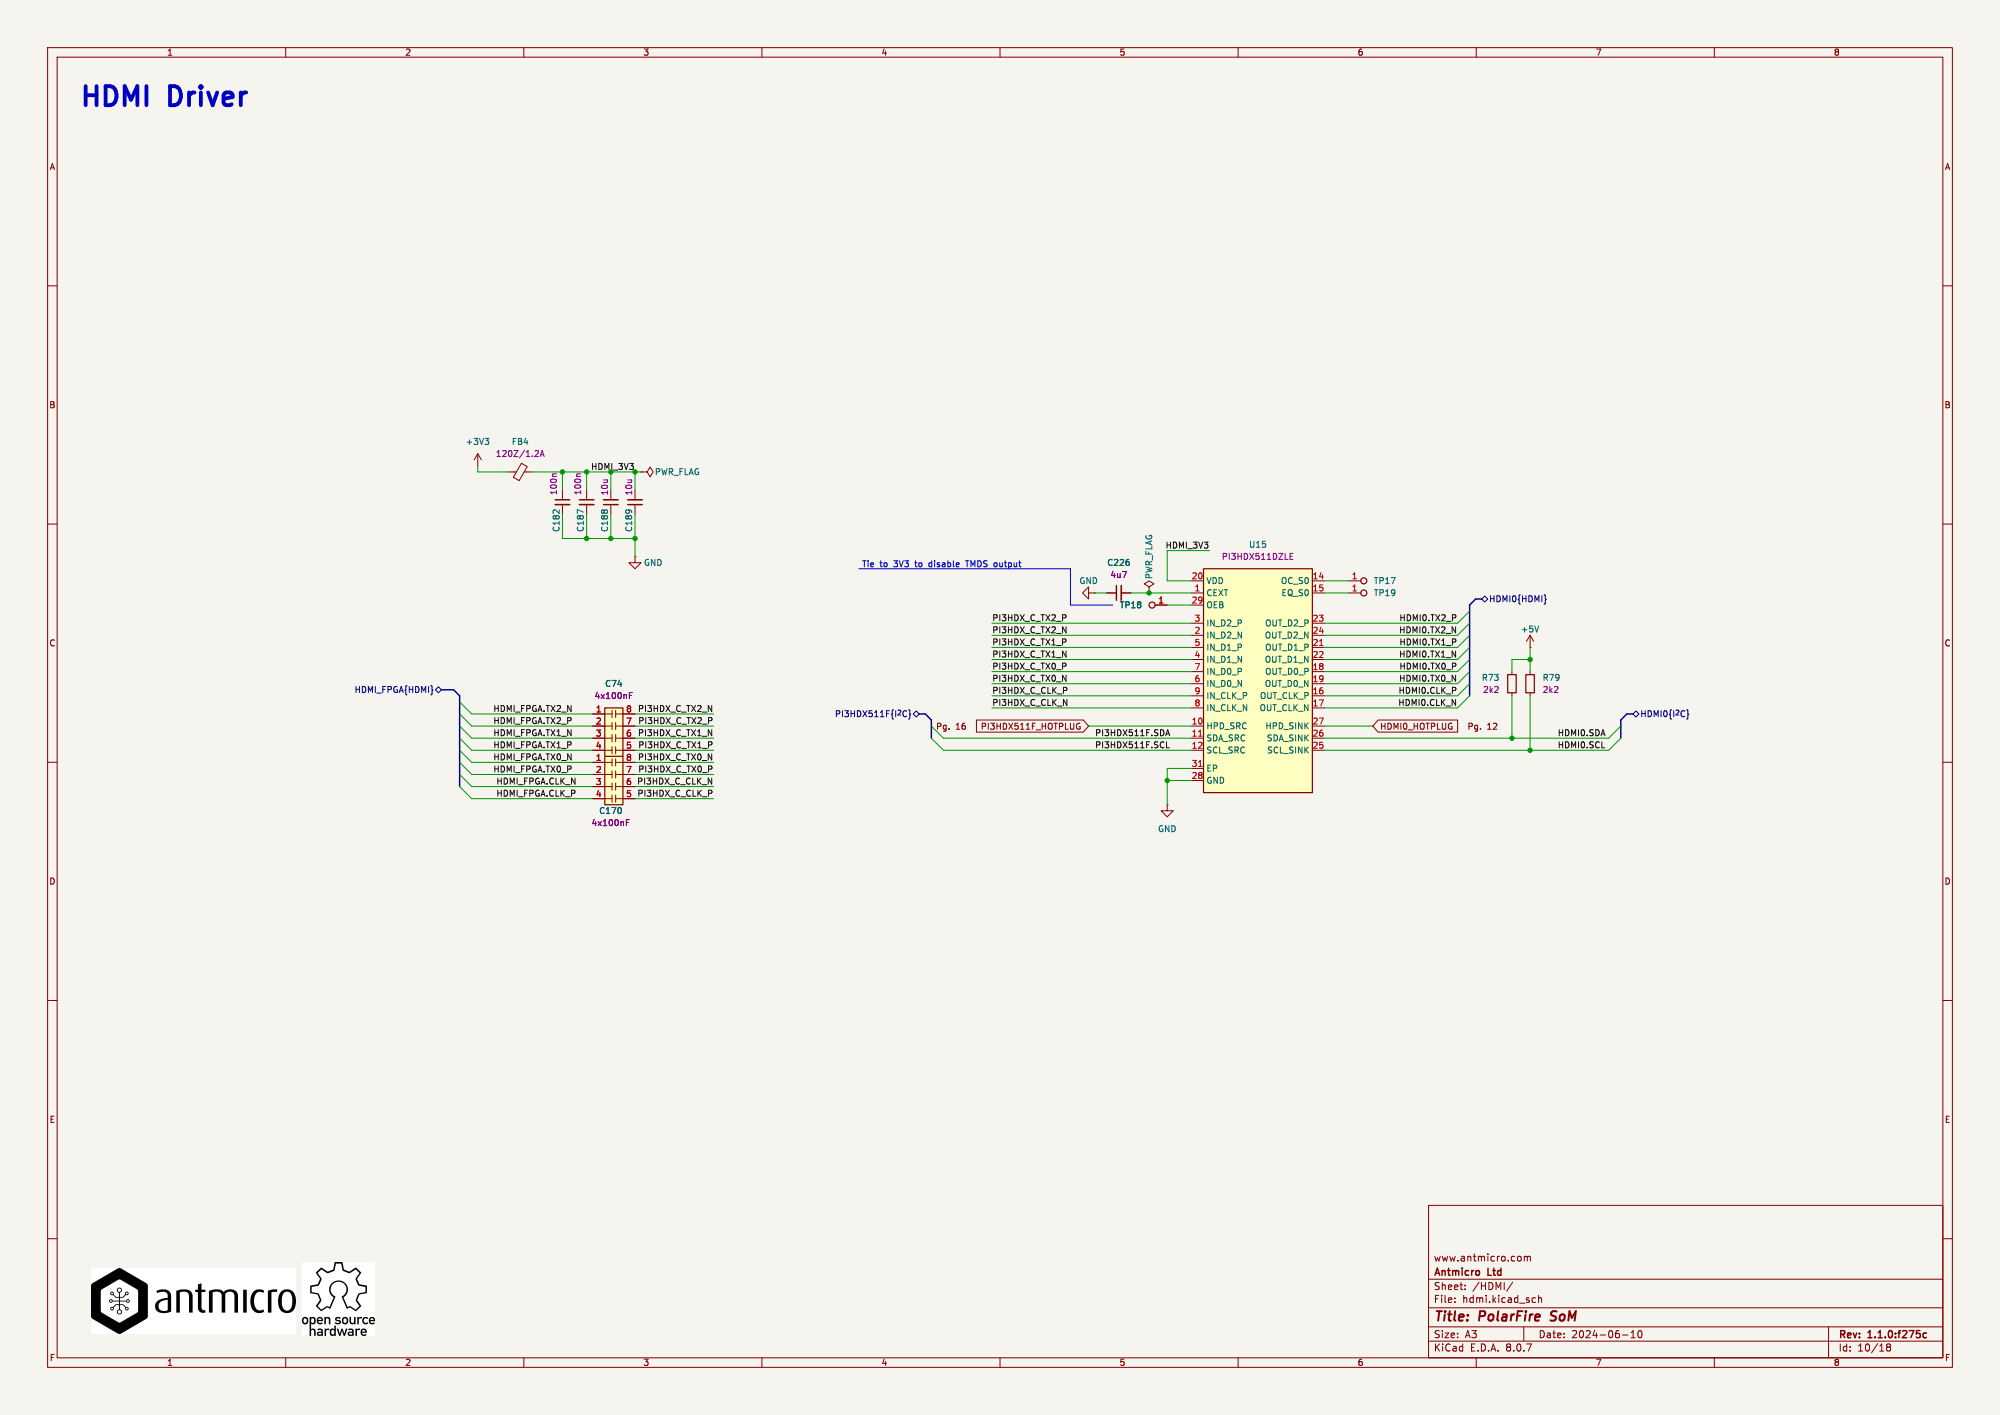
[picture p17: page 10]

HDMI0.SDA HDMI0.SCL Tie to 3V3 to disable TMDS output HDMI Driver

Id: 10/18 Title: PolarFire SoM

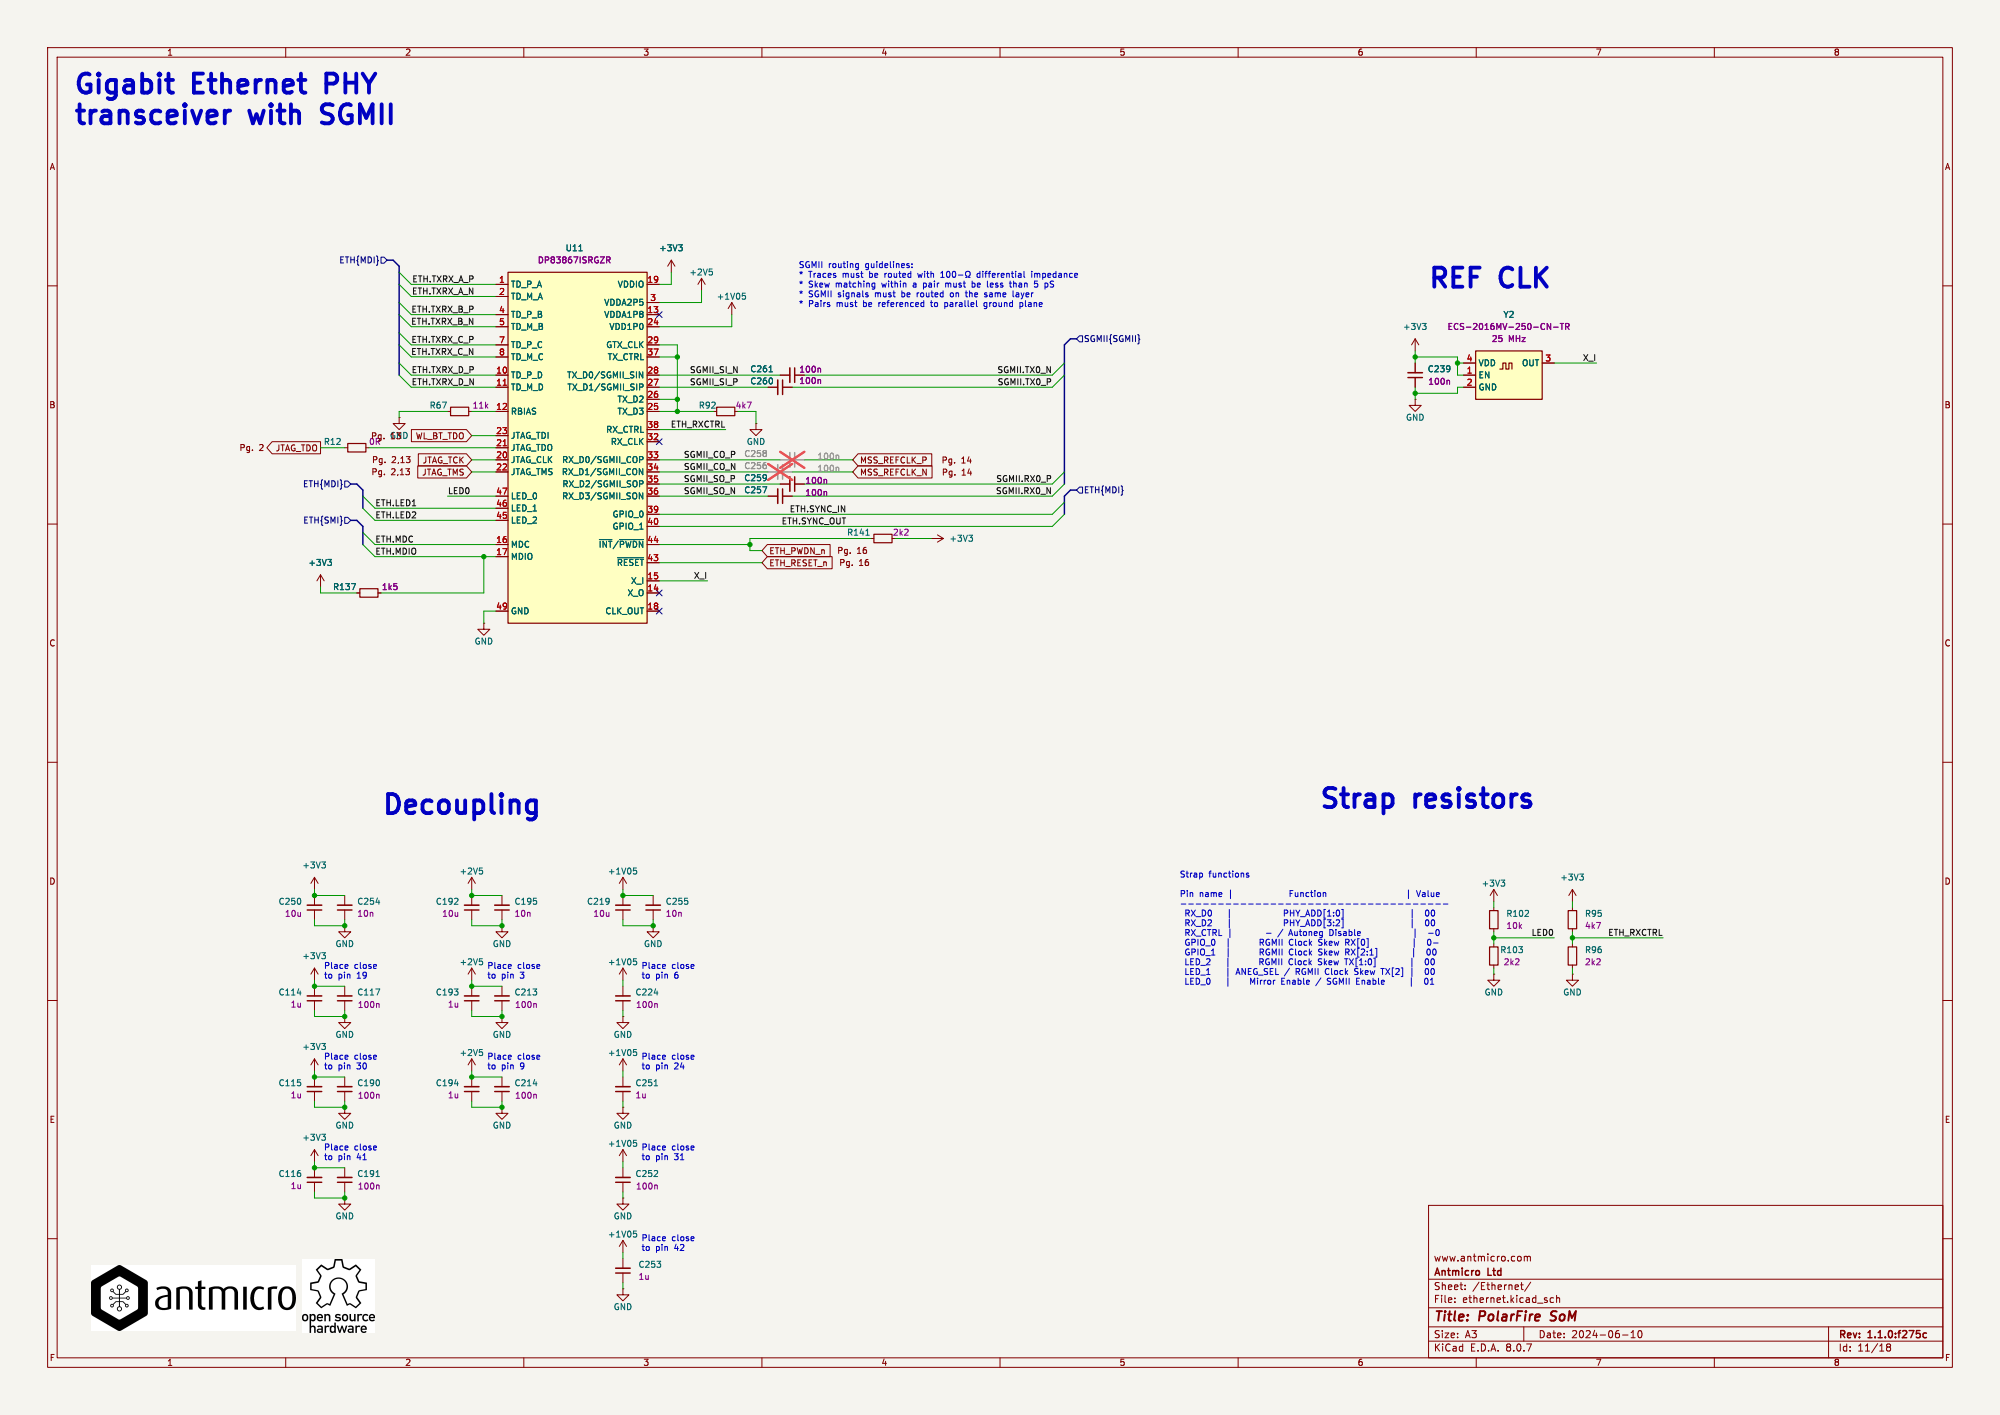
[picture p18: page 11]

Id: 11/18 Title: PolarFire SoM

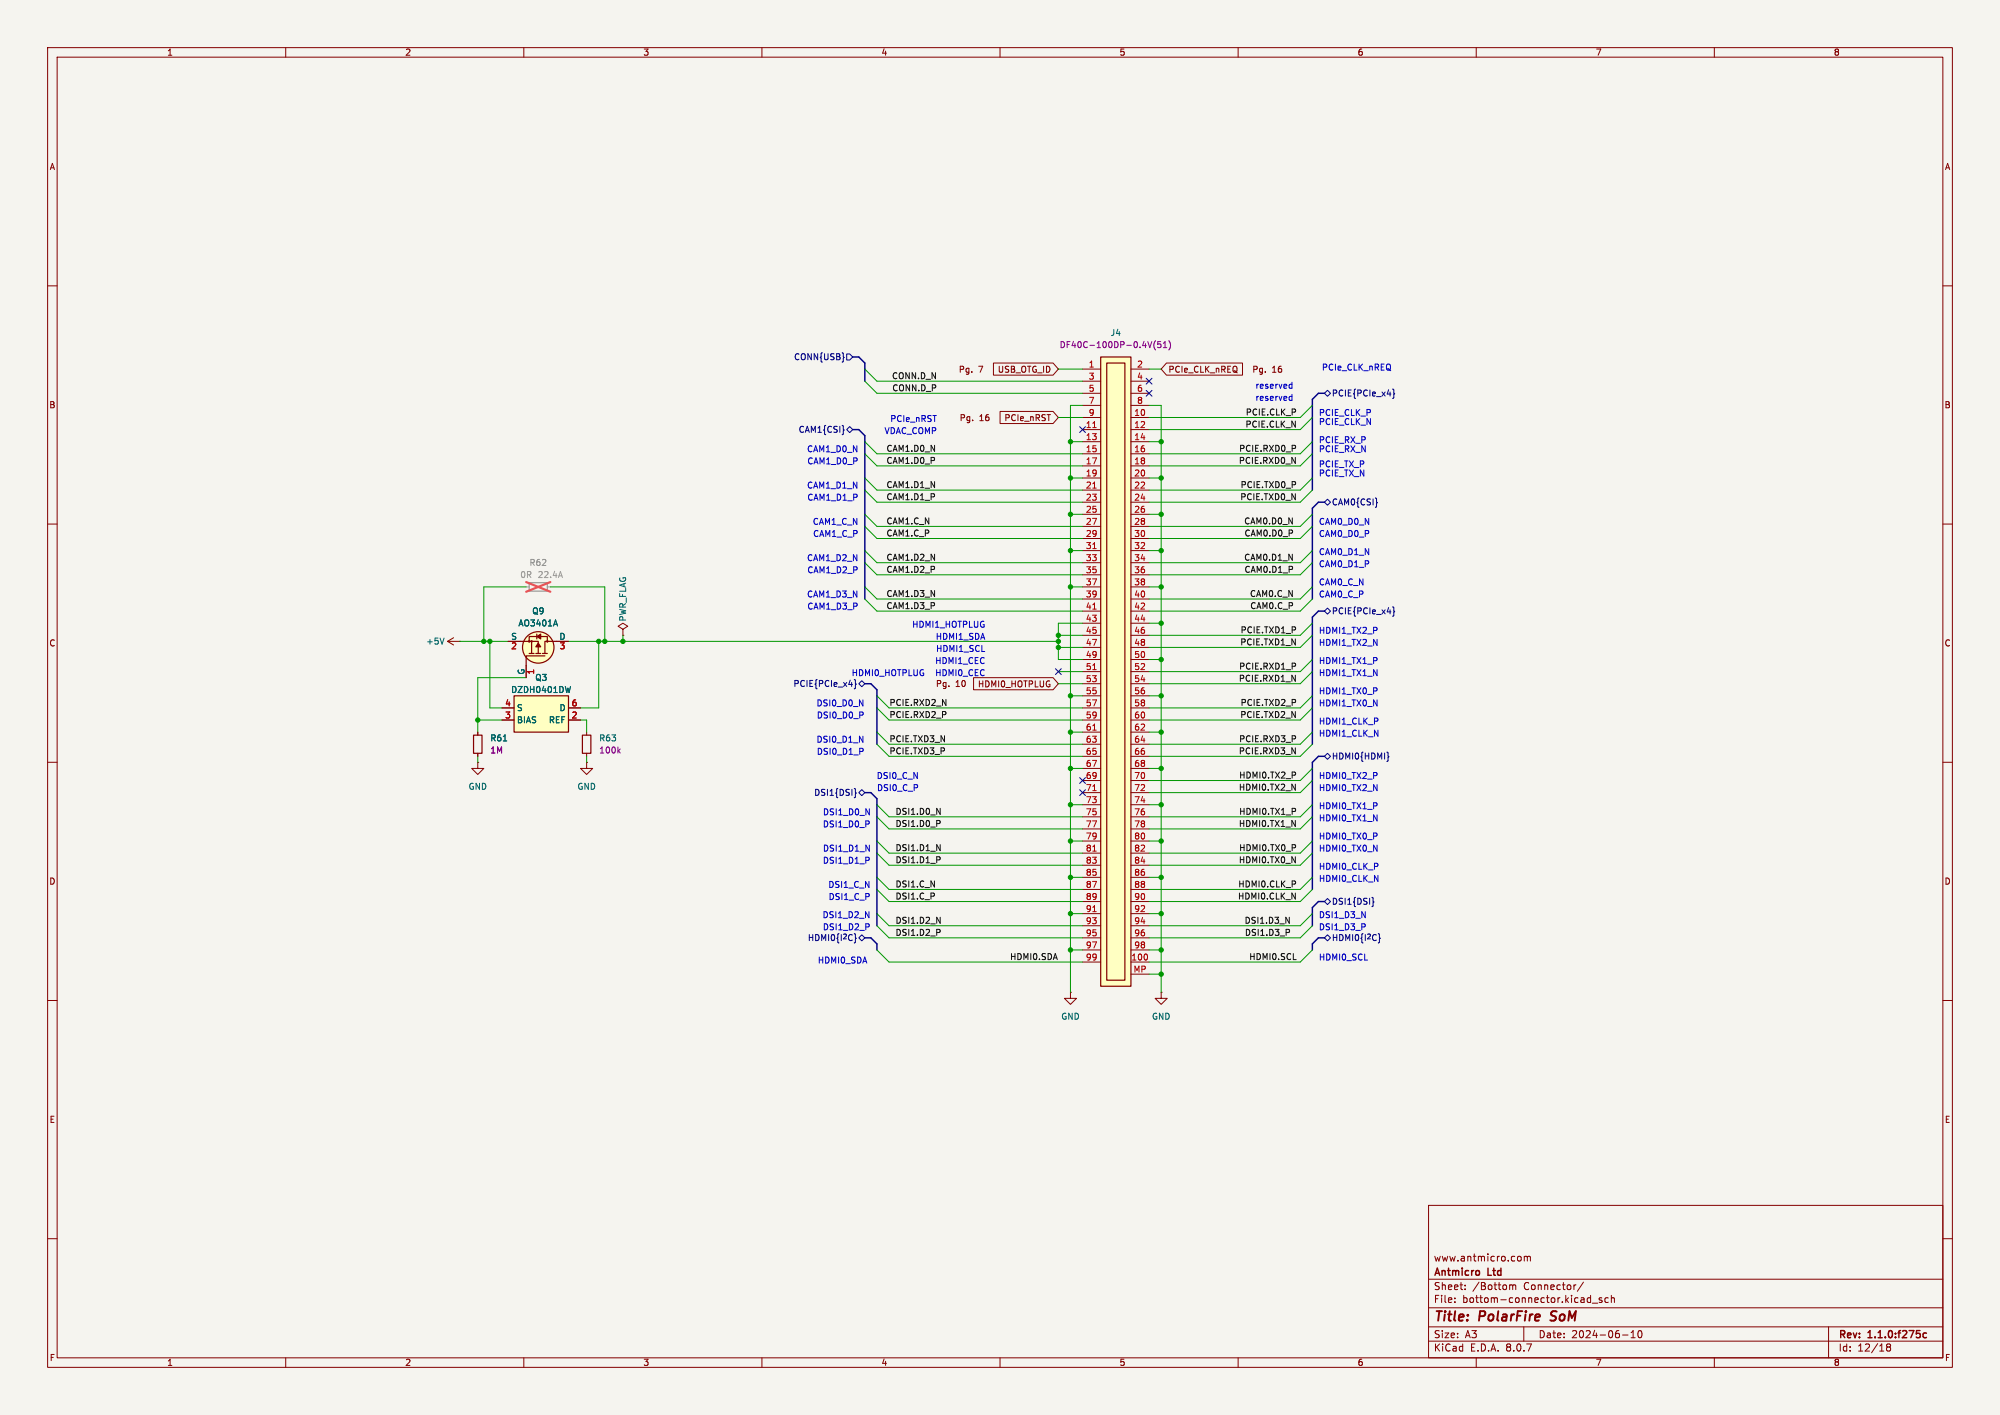
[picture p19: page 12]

Id: 12/18 Title: PolarFire SoM


I^{2}C0.SCL SD.DAT6 SD.DAT7 ETH.SYNC_OUT SD.CLK

Id: 13/18 Title: PolarFire SoM


WiFI and Bluetooth Module

Id: 13/18 Title: PolarFire SoM


Id: 14/18 Title: PolarFire SoM


set SD_PWR_ON to 3V3 on PF SoC PolarFire Bank 4
MSSIO

ID.SDA PolarFire Bank 2

ULPI.CLK ULPI.NXT ULPI.DIR

ULPI.DATA2 MEM.DAT7 MEM.CMD MEM.CLK MEM.STRB

ULPI.DATA6 ULPI.DATA5 EMMC.CLK

To use SD card on baseboard

ID.SCL SUPPLY.SDA

Id: 15/18 Title: PolarFire SoM


Id: 16/18 Title: PolarFire SoM


Id: 17/18 Title: PolarFire SoM

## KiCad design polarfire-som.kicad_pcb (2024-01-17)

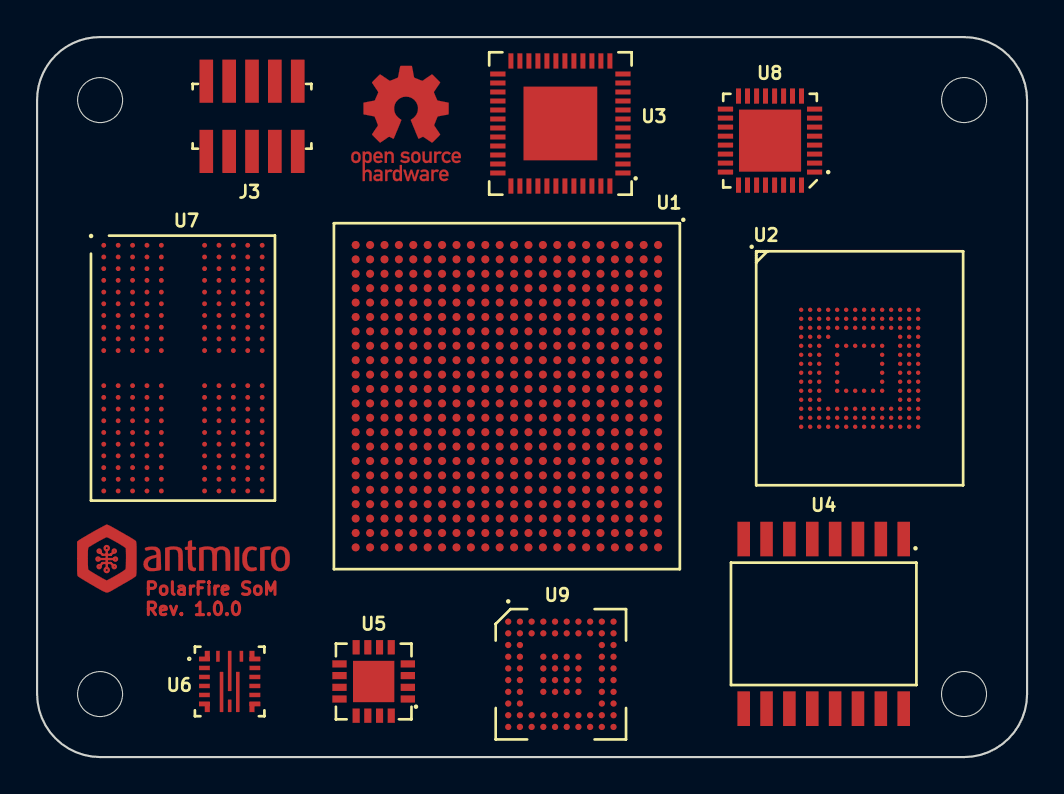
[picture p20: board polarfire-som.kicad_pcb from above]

Board: 2 copper layers, 55.0 x 40.0 mm, 17 parts (1 on the bottom side), 211 nets, no tracks yet.

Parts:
J1: CM4_Plug_Module_Hirose_DF40_2x50_DF40C-100DP-0.4V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; CM4_Module_Conn_Plug_Hirose_DF40_2x50_DF40C-100DP-0.4V
J3: PinHeader_2x5_P1.27mm_SMD
MP1, MP2, MP3, MP4: MP_NPTH_Drill2.5mm
N1: antmicro_logo; antmicro-logo_scaled_12mm
N2: oshw_logo; oshw-logo
U1: MPFS250T-FCVG484; BGA-484_19x19mm_Layout22x22_P0.8mm_FCVG484
U2: SDINBDG4-8G; BGA-196-153_11.5x13mm_Layout14x14_P0.5x0.5mm
U3: DP83867ISRGZR; VQFN-48_7x7mm_P0.5mm_EP4.1x4.1mm
U4: MT25QL01GBBB8E_SOP2-16; SOP2-16_7.5x10.3mm
U5: PAC1934_QFN; QFN-16-1EP_4x4mm_P0.65mm
U6: TPS65296; VQFN-HR-18_3.5x3.5x1mm
U7: MT53D512M32D2_WFBGA; BGA-200_10.0x14.5mm_Layout12x22_P0.80x0.65mm
U8: USB3300-EZK-TR; QFN-32-1EP_5x5mm
U9: CrossLink_LIF-MD6000-6JMG80I; BGA-80_7x7mm_Layout10x10_P0.65mm

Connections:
/LPDDR4/LPDDR4_CA0_A: U1.T5 (MSS_DDR_A0), U7.H2 (CA0_A), U7.R2 (CA0_B)
/LPDDR4/LPDDR4_CA1_A: U1.T6 (MSS_DDR_A1), U7.J2 (CA1_A), U7.P2 (CA1_B)
/LPDDR4/LPDDR4_CA2_A: U1.V7 (MSS_DDR_A2), U7.H9 (CA2_A), U7.R9 (CA2_B)
/LPDDR4/LPDDR4_CA3_A: U1.V6 (MSS_DDR_A3), U7.H10 (CA3_A), U7.R10 (CA3_B)
/LPDDR4/LPDDR4_CA4_A: U1.R6 (MSS_DDR_A4), U7.H11 (CA4_A), U7.R11 (CA4_B)
/LPDDR4/LPDDR4_CA5_A: U1.R5 (MSS_DDR_A5), U7.J11 (CA5_A), U7.P11 (CA5_B)
/LPDDR4/LPDDR4_CKE0_A: U1.K1 (MSS_DDR_CKE0), U7.J4 (CKE0_A), U7.P4 (CKE0_B)
/LPDDR4/LPDDR4_CK_C_A: U1.U4 (MSS_DDR_CK_N0), U7.J9 (CK_c_A), U7.P9 (CK_c_B)
/LPDDR4/LPDDR4_CK_T_A: U1.U5 (MSS_DDR_CK0/DDR_PLL0_OUT0), U7.J8 (CK_t_A), U7.P8 (CK_t_B)
/LPDDR4/LPDDR4_CS0_A: U1.L3 (MSS_DDR_CS0), U7.H4 (CS0_A), U7.R4 (CS0_B)
/LPDDR4/LPDDR4_DMI0: U1.AB4 (MSS_DDR_DM0), U7.C3 (DMI0_A)
/LPDDR4/LPDDR4_DMI1: U1.AA7 (MSS_DDR_DM1), U7.C10 (DMI1_A)
/LPDDR4/LPDDR4_DMI2: U1.Y10 (MSS_DDR_DM2), U7.Y3 (DMI0_B)
/LPDDR4/LPDDR4_DMI3: U1.T10 (MSS_DDR_DM3), U7.Y10 (DMI1_B)
/LPDDR4/LPDDR4_DQ0: U1.Y3 (MSS_DDR_DQ0), U7.B2 (DQ0_A)
/LPDDR4/LPDDR4_DQ1: U1.Y4 (MSS_DDR_DQ1), U7.C2 (DQ1_A)
/LPDDR4/LPDDR4_DQ2: U1.Y1 (MSS_DDR_DQ2), U7.E2 (DQ2_A)
/LPDDR4/LPDDR4_DQ3: U1.AA1 (MSS_DDR_DQ3), U7.F2 (DQ3_A)
/LPDDR4/LPDDR4_DQ4: U1.Y5 (MSS_DDR_DQ4), U7.F4 (DQ4_A)
/LPDDR4/LPDDR4_DQ5: U1.AA5 (MSS_DDR_DQ5), U7.E4 (DQ5_A)
/LPDDR4/LPDDR4_DQ6: U1.AB2 (MSS_DDR_DQ6), U7.C4 (DQ6_A)
/LPDDR4/LPDDR4_DQ7: U1.AB3 (MSS_DDR_DQ7), U7.B4 (DQ7_A)
/LPDDR4/LPDDR4_DQ8: U1.W8 (MSS_DDR_DQ8), U7.B11 (DQ8_A)
/LPDDR4/LPDDR4_DQ9: U1.W7 (MSS_DDR_DQ9), U7.C11 (DQ9_A)
/LPDDR4/LPDDR4_DQ10: U1.AB5 (MSS_DDR_DQ10), U7.E11 (DQ10_A)
/LPDDR4/LPDDR4_DQ11: U1.AA6 (MSS_DDR_DQ11), U7.F11 (DQ11_A)
/LPDDR4/LPDDR4_DQ12: U1.AB7 (MSS_DDR_DQ12), U7.F9 (DQ12_A)
/LPDDR4/LPDDR4_DQ13: U1.AB8 (MSS_DDR_DQ13), U7.E9 (DQ13_A)
/LPDDR4/LPDDR4_DQ14: U1.Y8 (MSS_DDR_DQ14), U7.C9 (DQ14_A)
/LPDDR4/LPDDR4_DQ15: U1.AA8 (MSS_DDR_DQ15), U7.B9 (DQ15_A)
/LPDDR4/LPDDR4_DQ16: U1.Y9 (MSS_DDR_DQ16), U7.AA2 (DQ0_B)
/LPDDR4/LPDDR4_DQ17: U1.W9 (MSS_DDR_DQ17), U7.Y2 (DQ1_B)
/LPDDR4/LPDDR4_DQ18: U1.AB9 (MSS_DDR_DQ18), U7.V2 (DQ2_B)
/LPDDR4/LPDDR4_DQ19: U1.AB10 (MSS_DDR_DQ19), U7.U2 (DQ3_B)
/LPDDR4/LPDDR4_DQ20: U1.V11 (MSS_DDR_DQ20), U7.U4 (DQ4_B)
/LPDDR4/LPDDR4_DQ21: U1.V10 (MSS_DDR_DQ21), U7.V4 (DQ5_B)
/LPDDR4/LPDDR4_DQ22: U1.Y11 (MSS_DDR_DQ22), U7.Y4 (DQ6_B)
/LPDDR4/LPDDR4_DQ23: U1.W11 (MSS_DDR_DQ23), U7.AA4 (DQ7_B)
/LPDDR4/LPDDR4_DQ24: U1.U8 (MSS_DDR_DQ24), U7.AA11 (DQ8_B)
/LPDDR4/LPDDR4_DQ25: U1.T8 (MSS_DDR_DQ25), U7.Y11 (DQ9_B)
/LPDDR4/LPDDR4_DQ26: U1.T11 (MSS_DDR_DQ26), U7.V11 (DQ10_B)
/LPDDR4/LPDDR4_DQ27: U1.U10 (MSS_DDR_DQ27), U7.U11 (DQ11_B)
/LPDDR4/LPDDR4_DQ28: U1.R11 (MSS_DDR_DQ28), U7.U9 (DQ12_B)
/LPDDR4/LPDDR4_DQ29: U1.R10 (MSS_DDR_DQ29), U7.V9 (DQ13_B)
/LPDDR4/LPDDR4_DQ30: U1.R8 (MSS_DDR_DQ30), U7.Y9 (DQ14_B)
/LPDDR4/LPDDR4_DQ31: U1.P8 (MSS_DDR_DQ31), U7.AA9 (DQ15_B)
/LPDDR4/LPDDR4_DQS0_N: U1.AA3 (MSS_DDR_DQS_N0), U7.E3 (DQS0_c_A)
/LPDDR4/LPDDR4_DQS0_P: U1.AA2 (MSS_DDR_DQS_P0), U7.D3 (DQS0_t_A)
/LPDDR4/LPDDR4_DQS1_N: U1.W6 (MSS_DDR_DQS_N1), U7.E10 (DQS1_c_A)
/LPDDR4/LPDDR4_DQS1_P: U1.Y6 (MSS_DDR_DQS_P1), U7.D10 (DQS1_t_A)
/LPDDR4/LPDDR4_DQS2_N: U1.AA10 (MSS_DDR_DQS_N2), U7.V3 (DQS0_c_B)
/LPDDR4/LPDDR4_DQS2_P: U1.AA11 (MSS_DDR_DQS_P2), U7.W3 (DQS0_t_B)
/LPDDR4/LPDDR4_DQS3_N: U1.V9 (MSS_DDR_DQS_N3), U7.V10 (DQS1_c_B)
/LPDDR4/LPDDR4_DQS3_P: U1.U9 (MSS_DDR_DQS_P3), U7.W10 (DQS1_t_B)
/LPDDR4/LPDDR4_ODT_CA_A: U1.L1 (MSS_DDR_ODT0), U7.G2 (ODT_CA_A), U7.T2 (ODT_CA_B)
/LPDDR4/LPDDR4_RESET_n: U1.L2 (MSS_DDR_RAM_RST_N/DDR_PLL0_OUT1), U7.T11 (RESET_n)
CAM1_C_N: J1.127, U9.A8 (DPHY0_CKN)
CAM1_C_P: J1.129, U9.B8 (DPHY0_CKP)
CAM1_D0_N: J1.115, U9.A7 (DPHY0_DN0)
CAM1_D0_P: J1.117, U9.B7 (DPHY0_DP0)
CAM1_D1_N: J1.121, U9.A9 (DPHY0_DN1)
CAM1_D1_P: J1.123, U9.B9 (DPHY0_DP1)
CAM1_D2_N: J1.133, U9.A6 (DPHY0_DN2)
CAM1_D2_P: J1.135, U9.B6 (DPHY0_DP2)
CAM1_D3_N: J1.139, U9.A10 (DPHY0_DN3)
CAM1_D3_P: J1.141, U9.B10 (DPHY0_DP3)
DSI1_C_N: J1.187, U9.A3 (DPHY1_CKN)
DSI1_C_P: J1.189, U9.B3 (DPHY1_CKP)
DSI1_D0_N: J1.175, U9.A2 (DPHY1_DN0)
DSI1_D0_P: J1.177, U9.B2 (DPHY1_DP0)
DSI1_D1_N: J1.181, U9.A4 (DPHY1_DN1)
DSI1_D1_P: J1.183, U9.B4 (DPHY1_DP1)
DSI1_D2_N: J1.193, U9.A1 (DPHY1_DN2)
DSI1_D2_P: J1.195, U9.B1 (DPHY1_DP2)
DSI1_D3_N: J1.194, U9.B5 (DPHY1_DP3)
DSI1_D3_P: J1.196, U9.A5 (DPHY1_DN3)
ETH_ TXRXM_C: J1.9, U3.8 (TD_M_C)
ETH_ TXRXM_D: J1.5, U3.11 (TD_M_D)
ETH_ TXRXP_B: J1.4, U3.4 (TD_P_B)
ETH_ TXRXP_D: J1.3, U3.10 (TD_P_D)
ETH_LED1: J1.15, U3.47 (LED_0)
ETH_LED2: J1.17, U3.46 (LED_1)
ETH_TXRXM_A: J1.10, U3.2 (TD_M_A)
ETH_TXRXM_B: J1.6, U3.5 (TD_M_B)
ETH_TXRXP_A: J1.12, U3.1 (TD_P_A)
ETH_TXRXP_C: J1.11, U3.7 (TD_P_C)
GND: J1.1, J1.2, J1.7, J1.8, J1.13, J1.14, J1.22, J1.23, J1.32, J1.33, J1.42, J1.43, J1.52, J1.53, J1.59, J1.60, J1.65, J1.71, J1.74, J1.98, J1.107, J1.108, J1.113, J1.114, J1.119, J1.120, J1.125, J1.126, J1.131, J1.132, J1.137, J1.138, J1.150, J1.155, J1.156, J1.161, J1.162, J1.167, J1.168, J1.173, J1.174, J1.179, J1.180, J1.185, J1.186
GPIO2: J1.58, U1.A8 (GPIO175PB1)
GPIO3: J1.56, U1.B8 (GPIO175NB1)
GPIO4: J1.54, U1.A6 (GPIO172PB1/CCC_SW_PLL1_OUT1)
GPIO5: J1.34, U1.C9 (GPIO176NB1/DQS)
GPIO6: J1.30, U1.D8 (GPIO174NB1)
GPIO7: J1.37, U1.H13 (GPIO185NB1)
GPIO8: J1.39, U1.H12 (GPIO182PB1/DQS)
GPIO9: J1.40, U1.G12 (GPIO182NB1/DQS)
GPIO10: J1.44, U1.D13 (GPIO2PB1/DQS)
GPIO11: J1.38, U1.C10 (GPIO176PB1/DQS/CCC_SW_PLL0_OUT0)
GPIO12: J1.31, U1.D9 (GPIO174PB1)
GPIO13: J1.28, U1.D6 (GPIO168NB1)
GPIO14: J1.55, U1.A7 (GPIO173PB1/CLKIN_S_3/CCC_SW_CLKIN_S_3)
GPIO15: J1.51, U1.H15 (GPIO7NB1)
GPIO16: J1.29, U1.C6 (GPIO171PB1/CLKIN_S_2/CCC_SW_CLKIN_S_2/C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)
GPIO17: J1.50, U1.H17 (GPIO8NB1/DQS)
GPIO18: J1.49, U1.G15 (GPIO7PB1)
GPIO19: J1.26, U1.B5 (GPIO170NB1/DQS)
GPIO20: J1.27, U1.C5 (GPIO170PB1/DQS/CCC_SW_PLL1_OUT0)
GPIO21: J1.25, U1.C4 (GPIO169PB1/CCC_SW_CLKIN_S_1)
GPIO22: J1.46, U1.F11 (GPIO181NB1)
GPIO23: J1.47, U1.F16 (GPIO11NB1)
GPIO24: J1.45, U1.D14 (GPIO2NB1/DQS)
GPIO25: J1.41, U1.E14 (GPIO9NB1)
GPIO26: J1.24, U1.B4 (GPIO169NB1)
GPIO27: J1.48, U1.G17 (GPIO8PB1/DQS/CCC_SE_PLL0_OUT0)
JTAG_RESET_n: J3.10, U1.H7 (DEVRST_N)
JTAG_TCK: J3.4, U1.E9 (TCK)
JTAG_TDI: J3.8, U1.G9 (TDI)
JTAG_TDO: J3.6, U1.E8 (TDO)
JTAG_TMS: J3.2, U1.F8 (TMS)
MSS_SGMII_RX0_N: U1.L6 (MSS_SGMII_RXN0), U3.36 (RX_D3_SGMII_SON)
MSS_SGMII_RX0_P: U1.L5 (MSS_SGMII_RXP0), U3.35 (RX_D2_SGMII_SOP)
MSS_SGMII_TX0_N: U1.N6 (MSS_SGMII_TXP0), U3.28 (TX_D0_SGMII_SIN)
MSS_SGMII_TX0_P: U1.N7 (MSS_SGMII_TXN0), U3.27 (TX_D1_SGMII_SIP)
unnamed: U1.A1 (VSS), U1.A4 (VSS), U1.A14 (VSS), U1.A22 (VSS), U1.AA4 (VSS), U1.AA14 (VSS), U1.AB1 (VSS), U1.AB11 (VSS), U1.AB22 (VSS), U1.B11 (VSS), U1.C8 (VSS), U1.C18 (VSS), U1.D5 (VSS), U1.D15 (VSS), U1.E2 (VSS), U1.E12 (VSS), U1.E20 (VSS), U1.E21 (VSS), U1.E22 (VSS), U1.F9 (VSS), U1.F18 (VSS), U1.F19 (VSS), U1.F20 (VSS), U1.G6 (VSS), U1.G16 (VSS), U1.G18 (VSS), U1.G22 (VSS), U1.H3 (VSS), U1.H20 (VSS), U1.J8 (VSS), U1.J10 (VSS), U1.J12 (VSS), U1.J14 (VSS), U1.J16 (VSS), U1.J22 (VSS), U1.K9 (VSS), U1.K11 (VSS), U1.K13 (VSS), U1.K15 (VSS), U1.K17 (VSS), U1.K20 (VSS), U1.L4 (VSS), U1.L10 (VSS), U1.L12 (VSS), U1.L14 (VSS), U1.L16 (VSS), U1.L18 (VSS), U1.L22 (VSS), U1.M1 (VSS), U1.M9 (VSS), U1.M11 (VSS), U1.M13 (VSS), U1.M15 (VSS), U1.M17 (VSS), U1.M19 (VSS), U1.M20 (VSS), U1.N10 (VSS), U1.N12 (VSS), U1.N14 (VSS), U1.N16 (VSS), U1.N18 (VSS), U1.N22 (VSS), U1.P5 (VSS), U1.P9 (VSS), U1.P11 (VSS), U1.P13 (VSS), U1.P15 (VSS), U1.P17 (VSS), U1.P20 (VSS), U1.R2 (VSS), U1.R18 (VSS), U1.R22 (VSS), U1.T9 (VSS), U1.T18 (VSS), U1.T19 (VSS), U1.T20 (VSS), U1.U6 (VSS), U1.U16 (VSS), U1.U20 (VSS), U1.U21 (VSS), U1.U22 (VSS), U1.V3 (VSS), U1.V13 (VSS), U1.W10 (VSS), U1.W20 (VSS), U1.Y7 (VSS), U1.Y17 (VSS)
unnamed: U1.A9 (VDDI1), U1.A19 (VDDI1), U1.B6 (VDDI1), U1.B16 (VDDI1), U1.C13 (VDDI1), U1.C21 (VDDI1), U1.D10 (VDDI1), U1.E17 (VDDI1), U1.F14 (VDDI1), U1.G11 (VDDI1)
unnamed: U1.AA9 (VDDI6), U1.AB6 (VDDI6), U1.N3 (VDDI6), U1.R7 (VDDI6), U1.T4 (VDDI6), U1.U1 (VDDI6), U1.U11 (VDDI6), U1.V8 (VDDI6), U1.W5 (VDDI6), U1.Y2 (VDDI6)
unnamed: U1.AA19 (VDDI0), U1.AB16 (VDDI0), U1.T14 (VDDI0), U1.V18 (VDDI0), U1.W15 (VDDI0), U1.Y12 (VDDI0), U1.Y22 (VDDI0)
unnamed: U1.C3 (VDDI2), U1.F4 (VDDI2), U1.G1 (VDDI2)
unnamed: U1.E7 (VDDI3), U1.J11 (VDDI3)
unnamed: U1.G21 (VDDA), U1.J21 (VDDA), U1.K19 (VDDA), U1.L21 (VDDA), U1.N21 (VDDA), U1.P19 (VDDA), U1.R21 (VDDA)
unnamed: U1.H8 (VDD25), U1.J17 (VDD25), U1.L15 (VDD25), U1.R9 (VDD25), U1.R17 (VDD25)
unnamed: U1.H14 (VDDAUX1), U1.H16 (VDDAUX1), U1.J9 (VDDAUX1), U1.J13 (VDDAUX1), U1.K10 (VDDAUX1)
unnamed: U1.H18 (XCVR_VREF), U1.H19 (XCVR_VREF)
unnamed: U1.J5 (VDDI4), U1.K2 (VDDI4)
unnamed: U1.J15 (VDD), U1.K12 (VDD), U1.K14 (VDD), U1.K16 (VDD), U1.L11 (VDD), U1.L13 (VDD), U1.L17 (VDD), U1.M12 (VDD), U1.M14 (VDD), U1.M16 (VDD), U1.N11 (VDD), U1.N13 (VDD), U1.N15 (VDD), U1.N17 (VDD)
unnamed: U1.J18 (VDDA25), U1.M18 (VDDA25)
unnamed: U1.K8 (VDDAUX2), U1.L9 (VDDAUX2)
unnamed: U1.K18 (VDD_XCVR_CLK), U1.P18 (VDD_XCVR_CLK)
unnamed: U1.M6 (VDDI5), U1.M8 (VDDI5)
unnamed: U1.M10 (VDDAUX4), U1.N9 (VDDAUX4)
unnamed: U1.P10 (VDD18), U1.P12 (VDD18), U1.P14 (VDD18), U1.P16 (VDD18), U1.R13 (VDD18)
unnamed: U2.A6 (VSS), U2.E7 (VSS), U2.G5 (VSS), U2.H10 (VSS), U2.J5 (VSS), U2.K8 (VSS)
unnamed: U2.C4 (VSSQ), U2.N2 (VSSQ), U2.N5 (VSSQ), U2.P4 (VSSQ), U2.P6 (VSSQ)
unnamed: U2.C6 (VCCQ), U2.M4 (VCCQ), U2.N4 (VCCQ), U2.P3 (VCCQ), U2.P5 (VCCQ)
unnamed: U2.E6 (VCC), U2.F5 (VCC), U2.J10 (VCC), U2.K9 (VCC)
unnamed: U3.3 (VDDA2P5), U3.9 (VDDA2P5)
unnamed: U3.13 (VDDA1P8), U3.48 (VDDA1P8)
unnamed: U3.19 (VDDIO), U3.30 (VDDIO), U3.41 (VDDIO)
unnamed: U3.6 (VDD1P0), U3.24 (VDD1P0), U3.31 (VDD1P0), U3.42 (VDD1P0)
unnamed: U7.A3 (VSS), U7.C1 (VSS), U7.C5 (VSS), U7.C8 (VSS), U7.D2 (VSS), U7.D4 (VSS), U7.D9 (VSS), U7.E1 (VSS), U7.E5 (VSS), U7.E8 (VSS), U7.G1 (VSS), U7.G3 (VSS), U7.G5 (VSS), U7.G8 (VSS), U7.J1 (VSS), U7.J3 (VSS), U7.K2 (VSS), U7.K4 (VSS), U7.K9 (VSS), U7.N2 (VSS), U7.N4 (VSS), U7.N9 (VSS), U7.P1 (VSS), U7.P3 (VSS), U7.T1 (VSS), U7.T3 (VSS), U7.T5 (VSS), U7.T8 (VSS)
unnamed: U7.A4 (VDD2), U7.A9 (VDD2), U7.F5 (VDD2), U7.F8 (VDD2), U7.H1 (VDD2), U7.H5 (VDD2), U7.H8 (VDD2), U7.K1 (VDD2), U7.K3 (VDD2), U7.N1 (VDD2), U7.N3 (VDD2), U7.R1 (VDD2), U7.R5 (VDD2), U7.R8 (VDD2)
unnamed: U7.A10 (VSS), U7.AB3 (VSS), U7.AB5 (VSS), U7.AB8 (VSS), U7.AB10 (VSS), U7.C12 (VSS), U7.D11 (VSS), U7.E12 (VSS), U7.G10 (VSS), U7.G12 (VSS), U7.J10 (VSS), U7.J12 (VSS), U7.K11 (VSS), U7.N11 (VSS), U7.P10 (VSS), U7.P12 (VSS), U7.T10 (VSS), U7.T12 (VSS), U7.V1 (VSS), U7.V5 (VSS), U7.V8 (VSS), U7.V12 (VSS), U7.W2 (VSS), U7.W4 (VSS), U7.W9 (VSS), U7.W11 (VSS), U7.Y1 (VSS), U7.Y5 (VSS), U7.Y8 (VSS), U7.Y12 (VSS)
unnamed: U7.AA3 (VDDQ), U7.AA5 (VDDQ), U7.AA8 (VDDQ), U7.AA10 (VDDQ), U7.B10 (VDDQ), U7.D12 (VDDQ), U7.F10 (VDDQ), U7.U3 (VDDQ), U7.U10 (VDDQ), U7.W1 (VDDQ), U7.W5 (VDDQ), U7.W8 (VDDQ), U7.W12 (VDDQ)
unnamed: U7.AB4 (VDD2), U7.AB9 (VDD2), U7.H12 (VDD2), U7.K10 (VDD2), U7.K12 (VDD2), U7.N10 (VDD2), U7.N12 (VDD2), U7.R12 (VDD2), U7.U5 (VDD2), U7.U8 (VDD2)
unnamed: U7.B3 (VDDQ), U7.B5 (VDDQ), U7.B8 (VDDQ), U7.D1 (VDDQ), U7.D5 (VDDQ), U7.D8 (VDDQ), U7.F3 (VDDQ)
unnamed: U7.F1 (VDD1), U7.G4 (VDD1), U7.G9 (VDD1), U7.T4 (VDD1), U7.T9 (VDD1), U7.U1 (VDD1)
unnamed: U7.F12 (VDD1), U7.U12 (VDD1)
unnamed: U8.1 (GND), U8.2 (GND), U8.33 (EP)
unnamed: U8.15 (VDD1.8), U8.26 (VDD1.8)
unnamed: U8.6 (VDD3.3), U8.16 (VDD3.3), U8.25 (VDD3.3), U8.30 (VDD3.3)
unnamed: U9.C1 (GND), U9.C10 (GND), U9.E5 (GND), U9.G2 (GND), U9.G5 (GND)
unnamed: U9.E4 (VCC), U9.E6 (VCC)
unnamed: U9.F5 (VCCIO1), U9.G4 (VCCIO1)
unnamed: U9.F6 (VCCIO2), U9.F7 (VCCIO2)
PAC1934_SCL: U1.F12 (GPIO181PB1), U5.4 (SM_CLK)
PAC1934_SDA: U1.F13 (GPIO184NB1), U5.5 (SM_DATA)
PCIe_CLK_N: J1.112, U1.L20 (XCVR_0A_REFCLK_N)
PCIe_CLK_P: J1.110, U1.L19 (XCVR_0A_REFCLK_P)
PCIe_RX1_N: J1.118, U1.G19 (XCVR_0_RX0_N)
PCIe_RX1_P: J1.116, U1.G20 (XCVR_0_RX0_P)
PCIe_RX2_N: J1.154, U1.K21 (XCVR_0_RX1_N)
PCIe_RX2_P: J1.152, U1.K22 (XCVR_0_RX1_P)
PCIe_RX3_N: J1.157, U1.M22 (XCVR_0_RX2_P)
PCIe_RX3_P: J1.159, U1.M21 (XCVR_0_RX2_N)
PCIe_RX4_N: J1.166, U1.R19 (XCVR_0_RX3_N)
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

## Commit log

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2024-01-17 [#52579] Add JTAG and connect it to SoC
    [connectors.kicad_sch, misc.kicad_sch, polarfire-som.kicad_sch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]
2024-01-17 [#52579] Add PAC1934 and connect it to SoC
    [polarfire-som.kicad_sch, soc.kicad_sch, supply.kicad_sch]
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2024-01-19 [#53847] Add TPD12S016 and connect HDMI to pfsom
    [hdmi.kicad_sch, polarfire-som.kicad_sch, soc.kicad_sch]
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2024-01-19 [#52577] Add power mux for bank 1, 2 and 4 supply
    [supply.kicad_sch]
2024-01-19 [#52577] Update PMIC's PVINVTT supply and GPO3 pullup
    [supply.kicad_sch]
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2024-01-19 [#54016] Add decoupling capacitors
    [#54016] Place decoupling capacitors at SoC sub-sheet
    [soc.kicad_sch]
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2024-01-22 [#54016] Add +5V on HDMI1 5V tolerant pins
    [connectors.kicad_sch]
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2024-01-26 [#53979] Resolve ethernet pin mapping
    [connectors.kicad_sch, ethernet.kicad_sch]
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2024-01-26 [#54202] Update PF BANK1 with alternative pin labels
    [soc.kicad_sch]
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2024-02-19 [#53847] Add HDMI to PF Bank 1 and remap colliding GPIOs
    [soc.kicad_sch]
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2024-02-19 [#53847] Connect Ethernet sync to PF Bank 1
    [connectors.kicad_sch, soc.kicad_sch]
2024-02-19 [#53847] Reconnect ETH sync pins to DP83867ISRGZR GPIOs
    [ethernet.kicad_sch, soc.kicad_sch]
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2024-02-19 [#54442] Connect reset and pwdn signals to PF
    [ethernet.kicad_sch, soc.kicad_sch]
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2024-02-19 [#54016] Add pull-up on pin 43 of CM4 connector
    [connectors.kicad_sch, polarfire-som.kicad_sch]
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2024-02-19 [#54491] Minor adjustments of labels and graphical items
    [connectors.kicad_sch, crosslink.kicad_sch, ethernet.kicad_sch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]
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2024-02-19 [#54178] Add WL and BT disable to WiFi module
    [connectors.kicad_sch, wifi_bt.kicad_sch]
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2024-02-19 [#54828] Add USB hub, change LBEE5PK2AE connection to USB
    [connectors.kicad_sch, usb.kicad_sch, wifi_bt.kicad_sch]
2024-02-19 [#54828] Add connections and external components to USB hub
    [connectors.kicad_sch, ethernet.kicad_sch, usb.kicad_sch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]
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2024-02-19 [#54491] Change VBAT in USB Phy to 3V3
    [usb.kicad_sch]
2024-02-19 [#54491] Update JTAG TRSTB connection to Bank 3
    [misc.kicad_sch]
2024-02-19 [#54491] Pull-up W# and HOLD# pins of SPI Flash
    [misc.kicad_sch]
2024-02-19 [#54016] Reconnect decoupling capacitors in more compact way
    [soc.kicad_sch]
2024-02-19 [#54491] Fix crystal calculations typo
    [ethernet.kicad_sch]
2024-02-19 [#54016] Add PAC1934 to MSSIO I2C_1, change USB hub default address
    [usb.kicad_sch]
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2024-02-19 [#54822] Add resistor to CRESET_B pin of MIPI CrossLink
    [crosslink.kicad_sch]
2024-02-19 [#54822] Add testpoint to CDONE pin of MIPI CrossLink
    [crosslink.kicad_sch]
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2024-02-19 [#53847] Add HDMI
    [#53847] Add HDMI driver power decoupling
    [hdmi.kicad_sch, soc.kicad_sch]
2024-02-19 [#54899] Add NC flag to Bank 5 of MPFS250T
    [ethernet.kicad_sch]
2024-02-19 [#54899] Add NC to QRDY pin of SDINBDG4
    [misc.kicad_sch]
2024-02-19 [#54899] Add pull-up resistors to Bank 3 of MPFS250T
    [misc.kicad_sch]
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2024-02-19 [#54899] Change value of R128 from 4k7 to 1k
    [misc.kicad_sch]
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2024-02-19 [#54899] Change Ethernet PHY power configuration to Two-Supply
    [ethernet.kicad_sch]
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2024-02-19 [#54899] Simplify power sequencing, add missing connections
    [connectors.kicad_sch, crosslink.kicad_sch, soc.kicad_sch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]
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2024-02-19 [#53847] Replace SN74LVC1T with SN74LVC1T45YZPR
    [hdmi.kicad_sch]
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2024-02-19 [#54899] Update level shifters symbols to glb libs
    [hdmi.kicad_sch]
2024-02-19 [#54899] Add ideal diode on HDMI1 5V input
    [connectors.kicad_sch]
2024-02-19 [#54899] Replace 330u capacitors
    [soc.kicad_sch]
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2024-02-19 [#54899] Change PF Bank 5 supply to 3V3
    [soc.kicad_sch]
2024-02-19 [#54899] Update USB labels and positions
    [#54899] Update pin types and ULPI regulators capacitors
    [usb.kicad_sch]
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2024-02-19 [#54899] Connect unused Ethernet PHY pins according to reference design
    [ethernet.kicad_sch]
2024-02-19 [#54899] Add backup UART and SDIO to WiFi module
    [soc.kicad_sch, usb.kicad_sch, wifi_bt.kicad_sch]
2024-02-19 [#54899] Fix duplicates
    [crosslink.kicad_sch]
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2024-02-19 [#55288] Change Ethernet PHY crystal to oscillator
    [ethernet.kicad_sch]
2024-02-19 [#54899] Change Bank 3 power supply to +3V3
    [soc.kicad_sch]
2024-02-19 [#55288] Add 100nF capacitors on PCIe TX lanes
    [pcie.kicad_sch]
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2024-02-19 [#55288] Replace PMIC, create initial placement
    [supply.kicad_sch]
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2024-02-19 [#55288] Replace Tag-Connect with test points
    [misc.kicad_sch]
2024-02-19 [#55288] Connect I2C to PMIC and Core supply
    [supply.kicad_sch, usb.kicad_sch]
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2024-02-19 [#54899] Swap USB lines
    [usb.kicad_sch]
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2024-03-01 [#55926] Reorder pins on memory selection resistor arrays
    [misc.kicad_sch]
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2024-03-05 [#56060] Replace HDMI Driver
    [hdmi.kicad_sch]
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2024-03-06 [#55690] Swap user LED channels
    [misc.kicad_sch]
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2024-03-07 [#55992] Replace 100n capacitors
    [connectors.kicad_sch, crosslink.kicad_sch, hdmi.kicad_sch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]
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2024-03-08 [#56060] Fix GND via to RESETB clereance
2024-03-08 [#56264] Add 4x100nF array and more GND via
    [hdmi.kicad_sch, pcie.kicad_sch]
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2024-03-11 Place cap arrays. Route PCIe. Start routing HDMI
    [hdmi.kicad_sch]
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2024-03-11 [#56232] Replace WL_BT module's inductor
    [wifi_bt.kicad_sch]
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2024-03-21 [#56715] Change resistor size, USB VDDIO and reset
    [connectors.kicad_sch, usb.kicad_sch]
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2024-03-22 [#56715] Improve HDMI0, add ID_SC and ID_SD connections
    [usb.kicad_sch]
2024-03-26 [#57038] Add clock sources and logic shifters, change ETH PHY supply
    [ethernet.kicad_sch, pcie.kicad_sch, soc.kicad_sch]
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2024-04-03 [#57422] Add 0R resistors on SENSE+ lines, swap USB lines
    [supply.kicad_sch, usb.kicad_sch]
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2024-04-03 [#57505] Start reworking schematic to hierarchical structure
    [bottom-connector.kicad_sch, connectors.kicad_sch, crosslink.kicad_sch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]
2024-04-04 [#57505] Simplify config of WL_BT module, add level shifters
    [fpga-gpio.kicad_sch, supply.kicad_sch, wifi_bt.kicad_sch]
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2024-04-05 [#57422] Add ETH PHY strap, WL_BT UART level shifter, fiducials, remove BYP_EN
    [ethernet.kicad_sch, fpga-mssio.kicad_sch, polarfire-som.kicad_sch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]
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2024-04-05 [#57505] Start moving logic level converters to GPIO sheet
    [bottom-connector.kicad_sch, crosslink.kicad_sch, ethernet.kicad_sch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]
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2024-04-11 [#57878] Fix power planes and bus naming
    [crosslink.kicad_sch, fpga-hsio.kicad_sch, polarfire-som.kicad_sch]
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2024-05-16 [#59453] Add 0R on +2V5, 2V5_CL and 1V8_CL rails
    [memory.kicad_sch, supply.kicad_sch]
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2024-05-27 [#59450] Remove custom CM4 connector, add CM4 outline with regular DF40C-100DP-0.4V(51) connectors
    [bottom-connector.kicad_sch, top-connector.kicad_sch]
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2024-06-04 [#60221] Swap USB switches channels
    [usb.kicad_sch]
2024-06-04 [#60204] Add pull-down on LPDDR4 RESET_n
    [lpddr.kicad_sch]
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2024-06-05 [#60500] Change ULPI.RESET connection, align schematics
    [fpga-gpio.kicad_sch, fpga-mssio.kicad_sch, polarfire-som.kicad_sch]
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2025-02-14 [#73079] Fix DSC557-0343FI1 symbol causing ERC violation
    [bottom-connector.kicad_sch, crosslink.kicad_sch, ethernet.kicad_sch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]
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2025-05-09 [#75091] Fix power monitor DNP configuration
    [supply.kicad_sch]
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2025-05-09 [#76082] Fix D5 orientation
    [supply.kicad_sch]
2025-05-09 [#76827] Update PolarFire MPN. Add test points. Modify DEVRST_N sequence. Bump revision
    [bottom-connector.kicad_sch, crosslink.kicad_sch, ethernet.kicad_sch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]
2025-05-09 [#76827] Fix C_47n_0402 MPN
    [fpga-supply.kicad_sch]
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2025-05-09 [#77309] Fix solder mask bridging and clean DRC
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2025-07-28 [#80745] HDMI DC coupling, KiCAD 9 bump + DRC fixes
    [bottom-connector.kicad_sch, crosslink.kicad_sch, ethernet.kicad_sch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]
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

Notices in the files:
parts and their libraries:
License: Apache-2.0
